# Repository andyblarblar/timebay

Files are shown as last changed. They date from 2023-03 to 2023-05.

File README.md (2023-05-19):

# Timebay

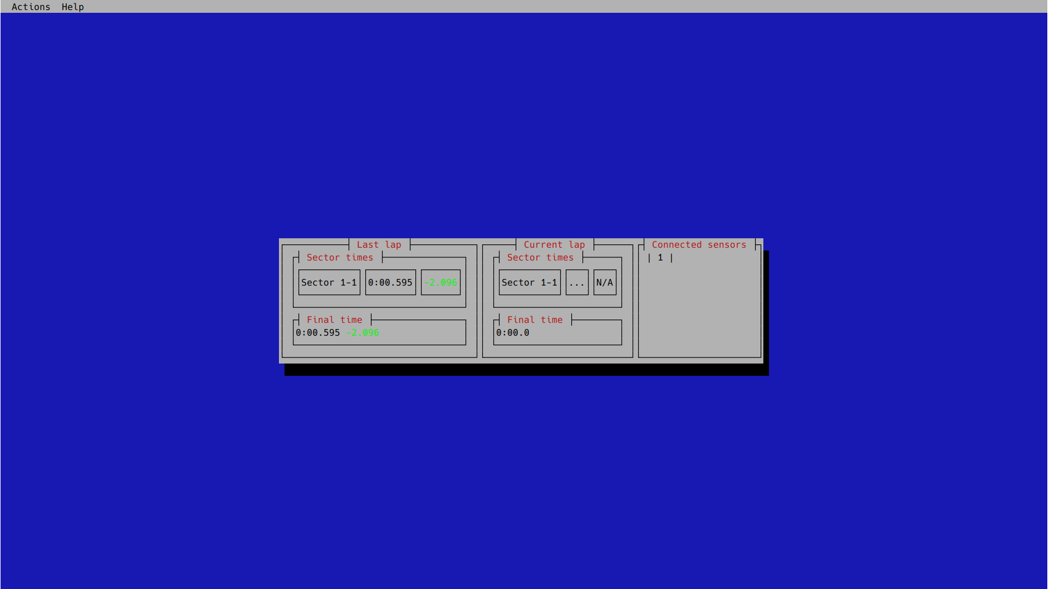
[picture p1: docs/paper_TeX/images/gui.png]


Timebay is a distributed system that provides two services to student vehicles in testing:
1. Sector timing (and splits)
2. Wireless network access

It does this by creating a mesh network of sensor nodes, where each sensor node contains a mesh point for other sensor nodes, 
vehicles, and clients to connect to. Timing data passes through this mesh, as does any user applications used, such as video feeds,
ROS topics and more. To connect to the timing services of Timebay, a TUI is provided.

For more details on the design, operations, and performance of Timebay, please see [the docs](./docs) and [the paper](./docs/Timebay.pdf).

Features:
- **Unlimited Scalability** - Add as many sectors as you need / can afford.
- **Resiliency** - Timebay is designed to do everything it can to ensure your practice day keeps moving. So long as one node keeps working, the system can continue smoothly operating, automatically healing if a node comes back online.
- **Flexibility** - Want to change up your sectors? Go ahead! Just press the zero sensors button when you're done and Timebay will handle all the routing needed to ensure smooth operation.
- **Expandability** - Want to add some other sensor to the network? Go ahead! Timebay provides scripts to connect any other Linux device to the network, allowing access from any other node.
- **Easy Setup** - Just plug the nodes in and go! The system will handle the networking for you.
- **Reasonable Accuracy** - Timebay has been measured to have 10ms error for each sector time in the worst case, and commonly as low as 3ms.
- **Low Cost** - Compared to professional sector timing systems, Timebay is a steal. Using Le Potatoes, the system costs under $100 per node! And remember, with Timebay, you're also getting your networking backbone alongside a sector timing system!
- **Maintainability** - Worried about patching tons of nodes if an issue is found? Don't! Timebay provides an update mechanism to easily update a dozen nodes at a time.

----
What Timebay should be used for:
- Providing online time splits for practice days
- Connecting networked equipment together throughout a circuit, such as cameras or channels for debugging
- Receiving non-critical information from the vehicle in motion, such as data for debugging, or ROS topics for visualisation

What Timebay should not be used for:
- Non-jitter-resistant networking to the vehicle in motion
  - Teleoperation, FPV, etc.
- Replacing a professional system where low error matters
  - Timebay has reasonably low error, but with 3 sectors ~9ms of error can matter a lot in professional events
- Data Collection
  - Timebay is currently designed for online data collection only, no logging is available (this could be added if required)

## Setup and Operation

To set up your own instance of Timebay or maintain an existing one,
please see [this document](docs/le-potato-setup.md).

## End User Instructions

> Required Items:
> - 1 Gateway node
> - 1-many Sensor nodes
> - Computer with TUI installed, and a way to connect an Ethernet cable
> - An Ethernet cable

> Note: None of the nodes are waterproofed (unless additional housing is provided). Check forecasts before deploying Timebay to prevent damage.

Set up:
1. Power the gateway node
2. Place and power all sensor nodes around the circuit, ordered so that they are passed in ascending order (skipping numbers is fine, like 1,2,4,6)
   1. If sensor nodes are not in order, then the system will assume the vehicle is cutting track
   2. Ensure all sensors have a solid object within 10m, so they can properly zero
   3. Ensure all sensors have at least 20cm between the object the sensor is hitting and the vehicle
   4. Ensure laps will take greater than 2s, else the debouncing on the sensor nodes will cause the vehicle to be ignored
3. Connect your computer to the Ethernet port on the gateway node
4. Run the TUI with `timebay_tui 192.168.0.1`
   1. This may display 'Connecting to broker...' if the system has not booted yet, or you have not received an IP. This will resolve itself in minutes. 
5. Wait for all nodes to display in the 'Connected Nodes' panel in the GUI. 
   1. Each node takes about 3 minutes to boot and connect to the mesh, so this may require a wait
   2. If a node does not appear after some time, then ensure that node is powered (indicated by a blinking blue). If it is, attempt to move the node closer to another node.
6. If external nodes are being used, run scripts/run_external_node.bash to connect them (this can be done at any time)
7. The system should now be ready to time. The system will begin when lowest ID node is passed, and automatically continue as laps are completed
   1. If the TUI crashes or seizes for some reason, simply close it and open again. This will lose splits, but will resume operation.

The system can be powered down abruptly and in any order without damage.

## Development

### Rust

The sensor node and client are both implemented in Rust. These are both in the /rust_ws folder, in a Rust workspace.

All of these applications can be developed without the nodes themselves, as they do not assume any hardware.

To run the sensor node using a fake instead of a real tf-luna, compile with the `no_sensor` feature enabled. This will
read a trigger every 3 seconds.

To integration test, there is a node simulator in node_sim. This can be used to test edge cases in the GUI or potential future
consumers of the detection data.

## Docker

Both nodes dockerfiles are at the top level. All files used in them are in the top level /scripts, /configs ect. directories.

Most scripts in /scripts have two versions, one for 802.11s, and one for batman-adv. All scripts for batman will have the 
postfix '_bat'. Both BATMAN-adv and 802.11s have their quirks. 802.11s works much better overall, but is pretty strict when it
comes to compatible hardware. BATMAN on the other hand is very compatible, but suffers from huge packet loss.

For convenience, there are build_x_node.bash scripts to build and tag the nodes correctly during development.

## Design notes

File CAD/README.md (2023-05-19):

# CAD

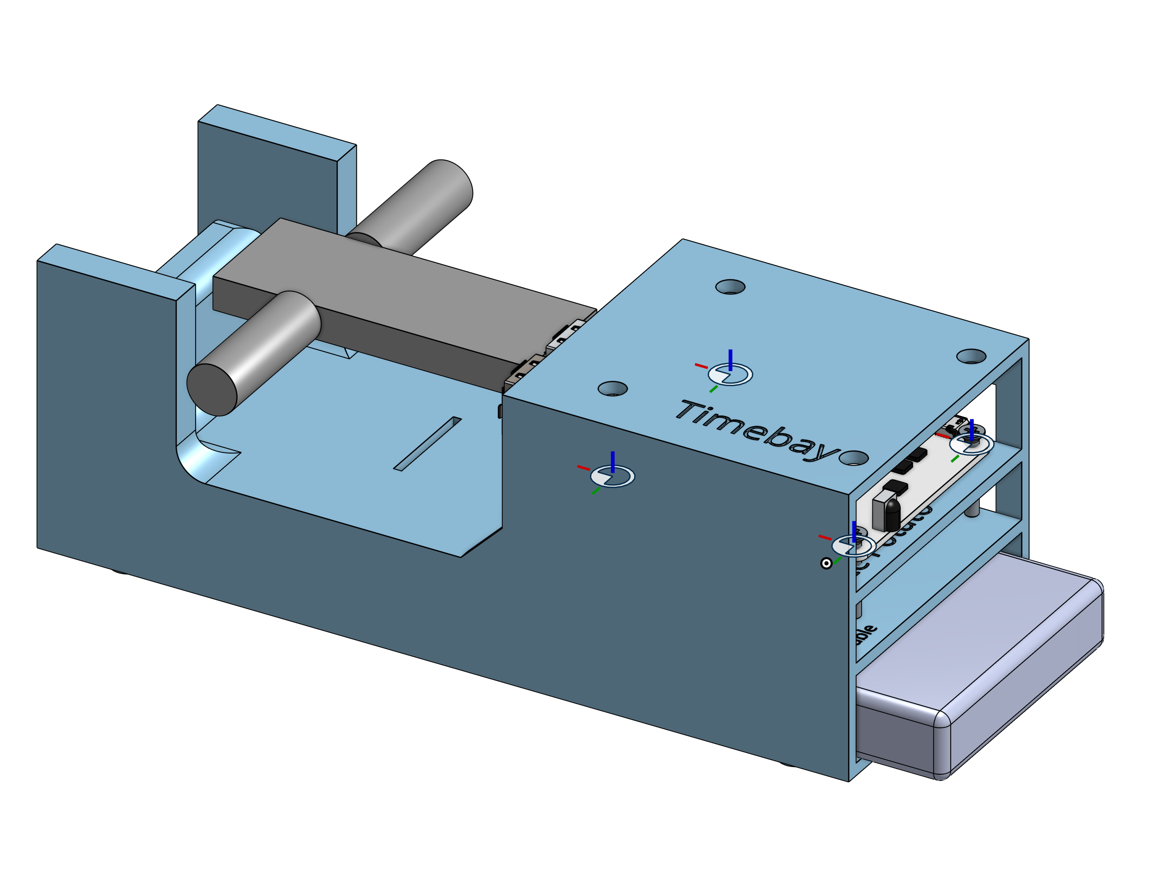
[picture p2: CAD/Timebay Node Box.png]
Box


This directory holds the CAD files for the boxes used to hold nodes.

View the OnShape
source [here](https://cad.onshape.com/documents/eca78c23cf623a8ee2aef306/w/7645614f6dc16000e8edd940/e/3784cc69f371b8e9440601d2).

I recommend printing these vertically if possible, as it significantly improves the print.

The slot in the middle of the box is designed to hold velcro, which can be used to extract the battery if it is pushed
into the
box (insert the Velcro from top to bottom first, then push in the battery, then pull the Velcro to remove battery)

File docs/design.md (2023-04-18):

# Design

This document has some notes on the design of the system

## Sensor node choices

- All mqtt use should be generic over client implementation. This means that we can swap in the case of issues with
  cross compiling ect.
- Dist sensors are debounced to avoid triggering on the same vehicle multiple times
- Mqtt payloads are postcard serialized structs
- Sensor threshold should always be > 160mm, since the sensor has +-16cm accuracy at worst
    - Note the 20cm blind spot, although this shouldn't matter much because the vehicle should never be that close
      anyhow.
- The dockerfile should be cross compilable to other archs, like MIPS
- While the TF-Luna does have an object detection mode that more or less eliminates the need for the dist sensor, I use
  the polling mode anyway, so we can swap to something like an ultrasonic sensor in the future with no code changes.
- Connected messages are sent continuously as a heartbeat, since when they are sent only once a late connecting GUI
  cannot
  discover the node.
- If a node has an internet connection at boot, it will attempt to OTA update itself by git pulling the timebay repo,
  then rebuilding the docker container.

## Networking choices

- Choice of layer 1:
    - 802.11 was chosen for its ability to maintain high throughput, for things like FPV driving
- Mesh interface config is done in the docker container, so that it can be run on any linux system without the need
  to worry about configuring it beforehand.
    - This is possible by using network=host
- ~~While 802.11s was initially chosen, it appears that the ability to bridge mesh interfaces was never actually~~
  ~~implemented~~
  ~~, despite being in the docs. [see](https://www.spinics.net/lists/linux-wireless/msg19548.html).~~
    ~~- This manifested as ARP frames being transmitted across the mesh, but not to the bridge (verified with wireshark).~~
      ~~This prevented eth0 from~~
     ~~being connected to the mesh, as well as DHCP from being served.~~
   ~~- 80211s on linux also seems pretty abandoned, with poor driver support (ex. rpi)~~
- So it turns out that under the rt2080 drivers, bridging is broken. On other drivers though, it works fine.
  - This is very important, since it turns out that BATMAN-adv causes massive packet loss when more than 2 nodes exist in the mesh
  - Because of this, 802.11s is likely the preferred protocol when drivers are available. 
- BATMAN-adv over IBSS is added as an alternative to 80211s as the meshing layer for timebay
    - Running over an IBSS means pretty much any interface can be used, although it does lock us into linux (so no MCU)
    - It also puts [an emphasis](https://www.open-mesh.org/projects/batman-adv/wiki/Wiki) on being able to be bridged,
      so it should solve our 80211s woes there
        - In particular, it's actually interface agnostic, and can even run over bluetooth and ethernet!
    - This is done by just changing the docker entrypoint to a different script, so we don't need duplicate containers
- In order to avoid latency in the system effecting lap times, detection messages will be timestamped globally when the
  detection occurs on device. This relies on
  all nodes having a synchronised clock.

## Client choices

- Client can survive disconnects
    - The current splits however will not, although this shouldn't be an issue since the client will be hardwired
- System can run with 1-2^16 nodes
    - Really only matters that we support the single sensor node case
- Sector notes:
    - Sector are defined by a starting and ending node, where the ending node is the next sector starting node
        - The last segment is an exception, as its end node is the first node.
    - Timing starts when first node is passed
        - Will not start if any other node is passed
    - If this is not the first lap, then immediately start the next lap when the last lap ends
        - This is needed as the last node of the last lap and the first node of this lap are the same, so we need count
          it as a trigger for both
    - Sectors are completed when their end node is triggered
    - If we jump a node, then mark any sector starting at the current segment and up to the segment ending with the node
      triggered as invalid.
        - We keep timing however, so we still get a final result
    - If we go back a node, invalidate the rest of the run
      - This covers the case where the last node dies, allowing the run to be reset to remove the dead node.
    - Node connection, disconnections, and reconnections are implicitly handled
        - New nodes are ignored
        - A node disconnecting will be handled by the following node being seen as a jump, invalidating the disconnected
          nodes sector
        - Because of this a node can disconnect and reconnect in the same run transparently so long as it triggers when
          it should
        - When the lap is done, the next lap will use the currently connected nodes, removing the dead nodes from the last lap.
        - If a new node is connected that becomes the first node, a full lap will be required before this lap can be recorded
          because the lap will be started in sector 2.
    - A run is done when the last non-invalidated segment is complete
- Sector times are calculated by the difference in time between the last completed sector and the next completed sector.
    - This means that if a sector is invalidated, the time spent in that sector will be rolled into the next.
- The client is designed such that it can be started before any other node on a cold start, and passively manage itself
  as the user connects the sensor nodes.
    - This should speed up setup, since one can visually determine if a node is connected by checking the clients screen
      from a distance.
- Client architecture:
    - The client uses a custom Elm like architecture, implemented on cursive, a TUI library.
    - The idea is basically that the gui holds no state, and will be completely redrawn when the backend updates.
        - The backend can only change state on reaction to messages, which are sent from the gui and from external
          sources, like MQTT.
    - The benefit of this system is that the gui will always match the state of the backend, which means that if we unit
      test the backend, that will implicitly also test the gui.
        - It also handles concurrency well, IMO
    - This is actually implemented by message passing between threads
        - The gui runs on the main thread, the backend runs on the backend thread, and async events (MQTT, gui updates
          ect)
          are processed on an eventloop thread.
        - The gui inputs have callbacks that send messages to the async thread
        - The async thread listens to mqtt and gui messages via polling, and merges the various sources to a common
          message
          type sent to the backend thread
    - When the backend thread receives a message, it passes it to an update function, which performs side effects on the
      apps state
        - Update can also return async tasks to run on the async thread, if we have a long-running side effect like
          sending a mqtt message
    - After running update, the whole gui is popped, and a new gui is rendered and pushed.

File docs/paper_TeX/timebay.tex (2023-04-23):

\documentclass[journal]{IEEEtran}
%
% If IEEEtran.cls has not been installed into the LaTeX system files,
% manually specify the path to it like:
% \documentclass[journal]{../sty/IEEEtran}

% Some very useful LaTeX packages include:
% (uncomment the ones you want to load)

% *** MISC UTILITY PACKAGES ***
%
%\usepackage{ifpdf}
% Heiko Oberdiek's ifpdf.sty is very useful if you need conditional
% compilation based on whether the output is pdf or dvi.
% usage:
% \ifpdf
%   % pdf code
% \else
%   % dvi code
% \fi
% The latest version of ifpdf.sty can be obtained from:
% http://www.ctan.org/pkg/ifpdf
% Also, note that IEEEtran.cls V1.7 and later provides a builtin
% \ifCLASSINFOpdf conditional that works the same way.
% When switching from latex to pdflatex and vice-versa, the compiler may
% have to be run twice to clear warning/error messages.

\usepackage{multirow}
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
% LaTeX2e). It also provides a command:
%\fnbelowfloat
% to enable the placement of footnotes below bottom floats (the standard
% LaTeX2e kernel puts them above bottom floats). This is an invasive package
% which rewrites many portions of the LaTeX2e float routines. It may not work
% with other packages that modify the LaTeX2e float routines. The latest
% version and documentation can be obtained at:
% http://www.ctan.org/pkg/stfloats
% Do not use the stfloats baselinefloat ability as the IEEE does not allow
% \baselineskip to stretch. Authors submitting work to the IEEE should note
% that the IEEE rarely uses double column equations and that authors should try
% to avoid such use. Do not be tempted to use the cuted.sty or midfloat.sty
% packages (also by Sigitas Tolusis) as the IEEE does not format its papers in
% such ways.
% Do not attempt to use stfloats with fixltx2e as they are incompatible.
% Instead, use Morten Hogholm'a dblfloatfix which combines the features
% of both fixltx2e and stfloats:
%
% \usepackage{dblfloatfix}
% The latest version can be found at:
% http://www.ctan.org/pkg/dblfloatfix

%\ifCLASSOPTIONcaptionsoff
%  \usepackage[nomarkers]{endfloat}
% \let\MYoriglatexcaption\caption
% \renewcommand{\caption}[2][\relax]{\MYoriglatexcaption[#2]{#2}}
%\fi
% endfloat.sty was written by James Darrell McCauley, Jeff Goldberg and 
% Axel Sommerfeldt. This package may be useful when used in conjunction with 
% IEEEtran.cls'  captionsoff option. Some IEEE journals/societies require that
% submissions have lists of figures/tables at the end of the paper and that
% figures/tables without any captions are placed on a page by themselves at
% the end of the document. If needed, the draftcls IEEEtran class option or
% \CLASSINPUTbaselinestretch interface can be used to increase the line
% spacing as well. Be sure and use the nomarkers option of endfloat to
% prevent endfloat from "marking" where the figures would have been placed
% in the text. The two hack lines of code above are a slight modification of
% that suggested by in the endfloat docs (section 8.4.1) to ensure that
% the full captions always appear in the list of figures/tables - even if
% the user used the short optional argument of \caption[]{}.
% IEEE papers do not typically make use of \caption[]'s optional argument,
% so this should not be an issue. A similar trick can be used to disable
% captions of packages such as subfig.sty that lack options to turn off
% the subcaptions:
% For subfig.sty:
% \let\MYorigsubfloat\subfloat
% \renewcommand{\subfloat}[2][\relax]{\MYorigsubfloat[]{#2}}
% However, the above trick will not work if both optional arguments of
% the \subfloat command are used. Furthermore, there needs to be a
% description of each subfigure *somewhere* and endfloat does not add
% subfigure captions to its list of figures. Thus, the best approach is to
% avoid the use of subfigure captions (many IEEE journals avoid them anyway)
% and instead reference/explain all the subfigures within the main caption.
% The latest version of endfloat.sty and its documentation can obtained at:
% http://www.ctan.org/pkg/endfloat
%
% The IEEEtran \ifCLASSOPTIONcaptionsoff conditional can also be used
% later in the document, say, to conditionally put the References on a 
% page by themselves.

% *** PDF, URL AND HYPERLINK PACKAGES ***
%
\usepackage{url}
% url.sty was written by Donald Arseneau. It provides better support for
% handling and breaking URLs. url.sty is already installed on most LaTeX
% systems. The latest version and documentation can be obtained at:
% http://www.ctan.org/pkg/url
% Basically, \url{my_url_here}.

% *** Do not adjust lengths that control margins, column widths, etc. ***
% *** Do not use packages that alter fonts (such as pslatex).         ***
% There should be no need to do such things with IEEEtran.cls V1.6 and later.
% (Unless specifically asked to do so by the journal or conference you plan
% to submit to, of course. )

\begin{document}
%
% paper title
% Titles are generally capitalized except for words such as a, an, and, as,
% at, but, by, for, in, nor, of, on, or, the, to and up, which are usually
% not capitalized unless they are the first or last word of the title.
% Linebreaks \\ can be used within to get better formatting as desired.
% Do not put math or special symbols in the title.
\title{Timebay: an Ad-Hoc Distributed System For Student Vehicle Testing}

\author{Andrew Ealovega}

\maketitle

\begin{abstract}
The University of Michigan Dearborn features many student vehicle teams that rely on test data to inform their innovations. Currently, each team has their own dedicated systems for testing, of varying quality and price. This paper introduces Timebay, a system that ergonomically provides testing infrastructure that can be shared across teams. Timebay is a network of sensor nodes that provide both online timing data for optimisation, as well as a reliable network connection to vehicles in motion for debugging and other uses. This is achieved by exploiting the observation that these two domains together create an environment compatible with mesh networking technologies, which can be used to enhance the user experience for both use cases. 
\end{abstract}

\section{Introduction}

\IEEEPARstart{T}{he} University of Michigan Dearborn (UMD) plays host to many competitive student organisations.
These organisations challenge students to form cross-functional teams with their peers to approach a common task (such as rocketry, robotics, etc.), before
pitting their solution against those of other schools across the country. Two of these teams, UMD-Racing and the Intelligent Systems Club, will be the focus of this paper.
    
UMD-Racing\footnote{https://umdearbornfsae.weebly.com} is UMD's Formula SAE Combustion team. Their competition has them build, test, and race a formula car over the span of a single school year. As part of their program, UMD-Racing performs extensive testing days to evaluate their work, and practice for competition. These testing days also serve another very important purpose outside of engineering however: driver training. FSAE competitions nearly always feature a kinetic component, where teams actually race their vehicles against each other in various formats. Because these vehicles can be rather challenging to drive, drivers must spend many hours in the vehicle to get used to its handling. The primary measurement of driver skill (although not the sole measurement) is of course lap times, which will become relevant shortly.

The Intelligent Systems Club\footnote{http://www.iscumd.com} (ISC) is UMD's general competitive robotics team. While ISC has competed in many kinds of events in the past, they are currently branding themselves as the schools autonomous racing team. Competing in the fledgling Autonomous Karting Series, ISC's primary project is the creation of a fully autonomous go-kart. Unlike UMD-Racing, ISC's vehicle does not feature a driver whatsoever, instead featuring a powerful, and networked, onboard computer. Like UMD-Racing, ISC performs testing days to evaluate performance. Once again, lap times are a useful metric of overall system performance. A challenge unique to ISC has been access to the onboard computer, since it must be headless. The solution to this classically has been to bring a home router to the testing site, as well as batteries to power it. 

Recently, both teams have run into issues with their testing. First, UMD-Racing currently does not have any sort of timing system, so driver performances are ranked using a manual stopwatch. This is obviously a rather course metric, which also lacks any sort of contextual data about where on course one driver may be performing better than another. Second, ISC lacks any sort of infrastructure for testing their new Kart. All of the prior stated timing issues also apply here, just with evaluating a model rather than a driver. In addition, the team has been aiming to make their systems more ergonomic compared to past projects, networking included. While the past router solution has worked, carrying around a full size router just for a single connection is rather wasteful. In addition, it suffers if the testing area gets too large for the single router to cover, which is more likely this year with the kart than with less mobile robots of the past.

I propose that both of these issues can be solved together, using a system dubbed \textit{Timebay} (a combination of the metric time, as well as highbay, the room on campus where the teams meet). To design Timebay, three primary design goals were identified from the prior requirements:
\begin{enumerate}
    \item Provide granular online lap time data
    \item Provide wide ranging network access to the vehicle
    \item Be reasonably ergonomic, such that those with little knowledge of IT can still operate the system
\end{enumerate}

Before we can begin to attempt to solve these goals together, we first need to investigate existing systems that solve them separately. To do this, we have identified a representative solution for each goal:

\begin{itemize}
    \item Goal 1: Sector timing systems
    \item Goal 2: Mesh networks
\end{itemize}

\section{Existing Solutions}

\subsection{Sector Timing}

In motor sports, a sector refers to a section of the full circuit. Sector times are thus simply the amount of time it took a driver to pass though a sector's bounds. This is similar and somewhat interchangeable with the term time splits or just 'splits'. Such a timing system is often complemented by time deltas, which are the differences in time taken between two laps in the same sector. For example, if a driver discovers a better way to enter a turn, their sector time will go down, and their time delta will report the empirical amount of time saved.

These systems are often used to compare two drivers performances, as well as analyse one's own performance while training. The primary advantage of using a sector timing system over a full course system is the introduction of context to the full lap time, since one can view where time was gained or lost around the course.

Most sector timing systems are implemented using a series of sensors around the course, with some sort of receiver on the car itself. As the car passes a sensor, its time is logged on the car, or alternatively some sort of central computer. An example of such a system is the MoTec BTX and BT2, which is the system UMD-Racing would use without Timebay \cite{motec}. These systems are quite expensive, as seen by the (at the time of writing) \$790.00 price \textit{per transmitter} in the MoTec system.

Upon interviewing UMD-Racing, they explained that the primary use of a sector timing for their student team would be for online information. This is because they already have advanced sensors for tracking position, but this data must be processed over a period of hours following practice. While training drivers, they could utilise the extra information given by a sector timing system to more scientifically iterate improvements. This makes a system like the above MoTec a difficult proposition, since it's a system designed for professional racing with many features UMD-Racing would not use. For UMD-Racing, timing data alone would suffice. 

\subsection{Mesh Networking}
Both teams operate in regions without existing network infrastructure. Thus, when supplying network access to the vehicle, we must utilise ad-hoc networking. One popular approach to ad-hoc networking is mesh networking.
Mesh networks, sometimes referred to as wireless mesh networks (WMN), are a network topology where the network is both managed and created by some set of stations. They are
highly dynamic, and need to handle network degradation or complete node loss gracefully \cite{1509968}. Relevant to this work are mesh networks created using WiFi, for
which there are two prominent implementations: BATMAN-adv and 802.11s.

\textbf{BATMAN-adv}: BATMAN-adv (better approach to mobile ad-hoc networking advanced) is a routing protocol for multi-hop ad-hoc networks \cite{open}. It operates on
OSI layer 2, and is implemented in an in-tree Linux kernel module, which makes it available on any reasonably modern Linux system. BATMAN-adv is rather interesting in that it can run over both wired and wireless networks. To do this, it operates over 
Linux network devices, ultimately providing a network device (bat0) as its API. This allows BATMAN-adv to be used over rather heterogeneous networks. Of note is that this means BATMAN-adv can be used to allow for multi-hop routing at layer 2 in 802.11 IBSS (ad-hoc) networks, which are normally single hop only.

\textbf{802.11s}: 802.11s is the mesh networking protocol implemented into the 802.11 standard itself \cite{article}. Being an 802.11 extension itself, 802.11s operates on layer 2. This does however mean that, unlike BATMAN-adv, 802.11s only works with devices both running WiFi and with drivers that support mesh mode operation. Linux does have support for 802.11s in its native driver stack, however only a few chip-set drivers actually implement this interface \cite{en:developers:documentation:ieee80211:802.11s}. Unlike BATMAN-adv, 802.11s does have the nice advantage of being usable with non-Linux devices, making it better at handling device heterogeneity.

Little existing works investigate the use of these protocols in vehicular mobility. \cite{zeiger2009mobile} Found BATMAN was ill suited to robotic teleoperation with its default settings, but could work spottily with some adjustments. In \cite{8746361}, the authors find BATMAN-adv to be more capable of handling mobile scenarios then rival protocols, given a predictive extension. In \cite{8417706}, the authors investigate 802.11s under high speeds. They found applications resistant to jitter could run over the connection, although jitter sensitive connections like voice and video could not.

For ISC's use case, mobile connections to the vehicle would be highly desirable, but not necessarily required. This is because there are still many use cases where having the vehicle parked somewhere on the circuit with network access would be valuable.

\section{Design}

The design of Timebay is based around the key observation that goals 1, when implemented using a sector timing system, and 2, when implemented as a mesh network, lead to a physically similar topology (visualised in fig. \ref{fig:node_sensor_compare}). This naturally occurs because both systems want to be close to the car. The sector system does this for contextual data, and the mesh network does this for coverage. This makes these two solutions naturally complementary. As the car goes around the circuit, it will pass by sensors to read its sector time. If we also add networking to these sensors, then the car can also move its connection to that local sensor node. Further, these sensor nodes will be spread somewhat equally across the track. Given these nodes form a mesh network, the mesh will be able to form around obstacles that would have otherwise blocked a directional signal from a single station (such as the home router ISC uses).

\begin{figure}[t]
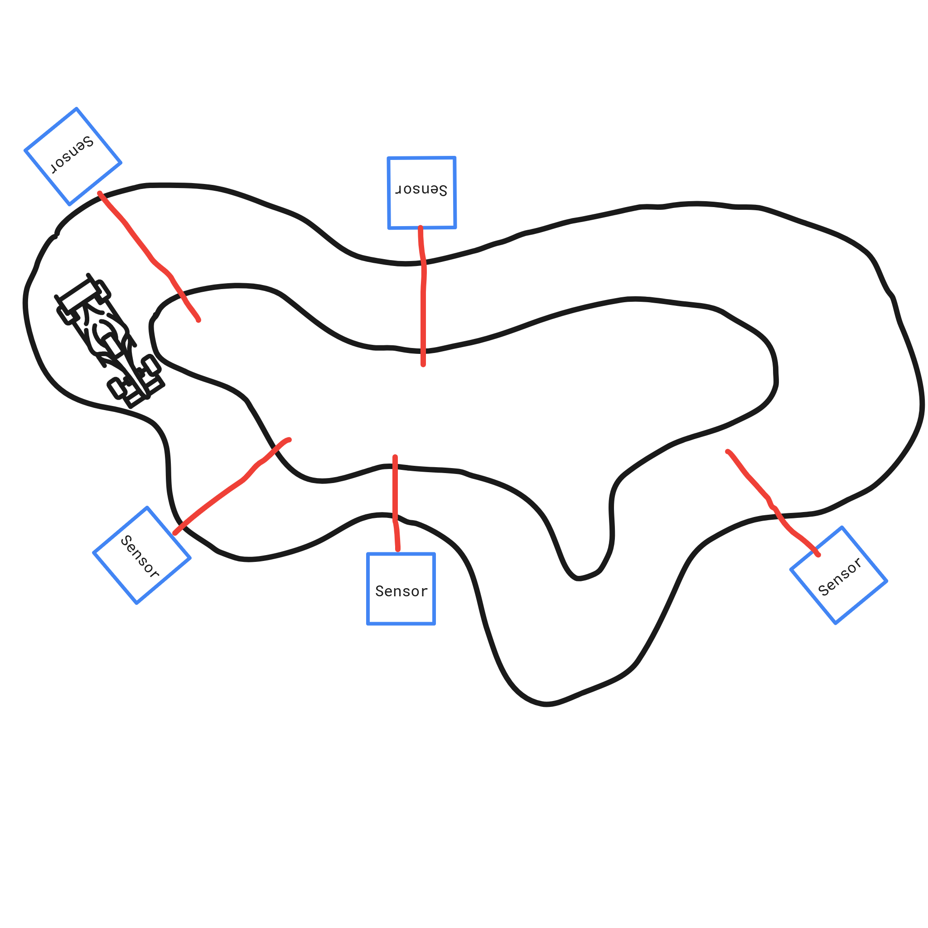
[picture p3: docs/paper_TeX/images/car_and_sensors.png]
    
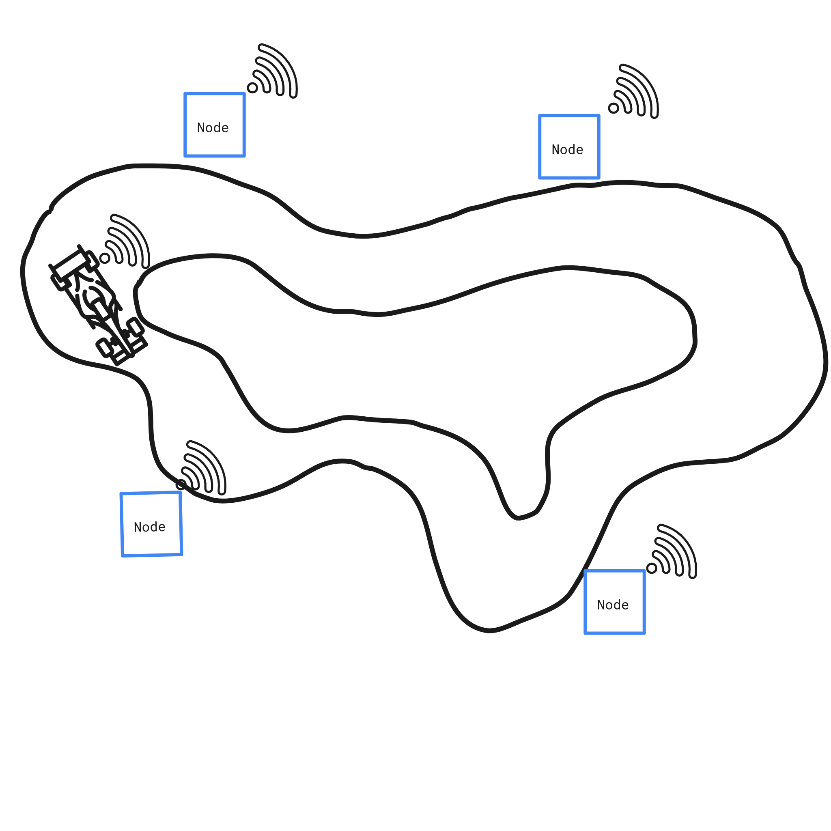
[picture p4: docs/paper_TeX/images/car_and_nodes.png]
    
    \caption{A visualisation of the physical similarities between a mesh network and sector timing system}
    \label{fig:node_sensor_compare}
\end{figure}

This sensor-mesh approach also conveniently handles part of our third goal, ergonomics. Mesh networks are, by definition, self organising. This means that they avoid many of the intricacies of setting up an AP for an end user since they can just be pre-configured by the creator. These mesh networks will also be more resilient to interference, since they can naturally route around something like a locally strong EMF. This should assist in abstracting away the complexities of networking from the user.

There is an issue with using a mesh network approach however. For either use case, an end user cannot get information out of the the network without also using a mesh compatible machine. This goes against our ergonomic goal. To solve this, we introduce a gateway node, which is simply a node that allows for access to the mesh network without participating in the mesh itself. End users will attach their computers to this node, allowing the mesh network to be abstracted away. To aid in 
debugging the mesh network from outside, a GUI will be developed that displays sensor node connection status.

\subsection{Components}
In summary, Timebay is comprised of:

\textbf{Sensor Nodes} - Nodes that handle both detection of a passing vehicle and organisation of the mesh network. Timebay should support 1-many sensor nodes in a network, where each sensor node is allocated a unique identifier. These nodes are fully wireless and battery powered to ease setup.

\textbf{Gateway Node} - A node that serves as the single entry point to the mesh, and Timebay as a whole. This node should have two network interfaces. One participates in the mesh, and the other allows for access to the mesh (via NAT, bridging or otherwise). Any centralised components of Timebay should also run on this server, such as network management utilities or databases.

\textbf{External Nodes} - Guests that participate in the mesh, but are not sensor nodes. These nodes use the mesh simply for its network access to the gateway or other external nodes. An example of an external node would be ISC's onboard PC.

\textbf{Clients} - End user computers that have no mesh compatibility. These are off the shelf laptops that may be running one of many OSes. Clients should connect to the external network interface on the gateway node to access all network resources. A cross-platform GUI application will be provided that will handle access to all of Timebay's timing functions.

\begin{figure}[t]
    \centering
    
    \caption{High level network topology}
    \label{fig:high_level_net}
\end{figure}

\section{Implementation}

\subsection{Hardware}
\textbf{Nodes} - Our node implementation uses the Libre Compute Le Potato single board computer. This is a Raspi3 like board that has an 800Mhz processor, 2Gb RAM, and 1/100 Ethernet. To allow for wireless connectivity, we use ALFA AWUS036ACM (mt7612u chipset) wireless adapters.

\textbf{Sensor Nodes} - Vehicle detection will be preformed using a TF-Luna laser distance sensor. This sensor will be used like a line break sensor, detecting the vehicle when an object is detected some threshold closer than the zero point.

\textbf{Gateway Node} - Clients will connect to the gateway node using it's Ethernet port.

\begin{figure}[t]
    \centering
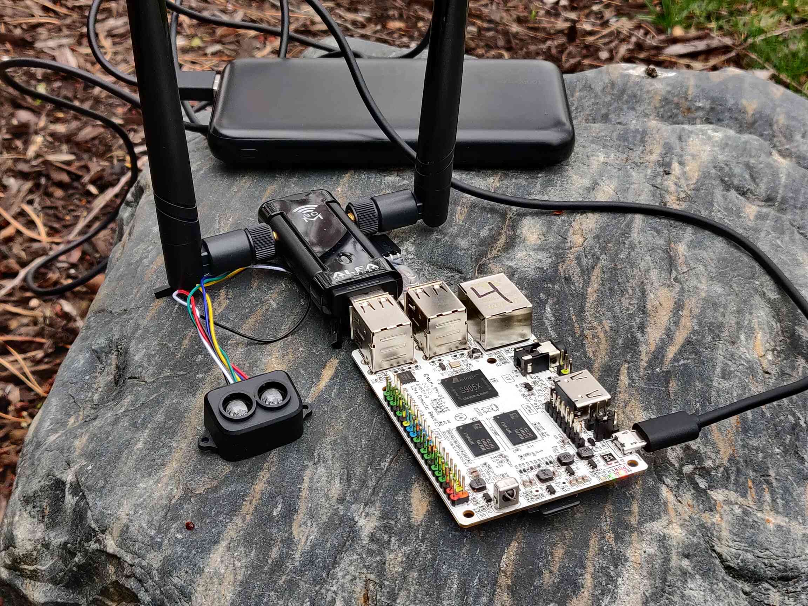
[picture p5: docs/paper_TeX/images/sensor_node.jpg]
    
    \caption{A sensor node}
    \label{fig:node}
\end{figure}

\subsection{Network}

The first key decision required for Timebays network implementation is a choice of physical layer protocol. Three main protocols were considered during this process.

\begin{itemize}
    \item \textbf{WiFi} - High bandwidth commodity standard
    \item \textbf{Bluetooth} - Low bandwidth, low power
    \item \textbf{Zigbee} - Lowest bandwidth, commonly used in mesh networks
\end{itemize}

Overall, Zigbee is likely the most fitting protocol, since it allows for using very low power devices for sensor nodes, and natively supports mesh networks. For Timebays use case however, Zigbee's middling 250Kbps bandwidth is simply too slow for some of the more intense activities ISC may perform \cite{haque_abdelgawad_yelamarthi_2022}. For example, creating an FPV video setup would require bandwidth well into the tens of megabits, which only WiFi supplies. For this reason, WiFi was chosen as the wireless protocol.

For our layer 2 mesh protocol, Timebay implements both a BATMAN-adv and 802.11s option. This is done due to the lack of conclusive evidence supporting either protocol as being definitively superior in the context of mobility. Additionally, little documentation exists regarding the current state of each project, or their associated hardware quirks.

All nodes get dynamic IPs in the 192.168.0.0/24 subnet, allocated by a DHCP server on the gateway node. The gateway node itself has the static IP 192.168.0.1, to allow for connections to centralized resources. DHCP was chosen over static IPs to allow for scaling the number of external nodes in mesh without requiring the user to maintain a record of allocated addresses.

To allow for clients to connect to the mesh network, the gateway node creates a Linux bridge interface between its Ethernet port and its mesh interface. The gateway node is only accessed via the IP address on the bridge, so clients connecting to the mesh can access any other mesh node as if they themselves were on the mesh. This also allows for clients to receive DHCP addresses, as DHCP will flow over the bridge. 

\subsection{BATMAN-adv Configuration}
BATMAN-adv is by default not very mobile friendly, as discussed in \cite{zeiger2009mobile}. Borrowing from that work, we will configure BATMAN to send OGM every 50ms. The goal of this is to minimize the time it takes for the mesh to reconfigure routes, critical to ensure dead nodes are routed around and mobile external nodes quickly change mesh links. To aid in this, OGM aggregation is also disabled, as recommended by the BATMAN-adv docs \cite{tweaking}. Both of these configurations will likely lower throughput, but should hopefully improve persistence in exchange. Following the results of \cite{8421863}, we will be using BATMAN IV over V.

\subsection{Sensor Node Communication}

All data related to the timing features of Timebay are broadcast across the network using MQTT. MQTT was chosen in this case not for its low bandwidth requirements (although this is nice), but rather its convenient pub-sub architecture which naturally mixes well with our highly dynamic network topology. The MQTT broker for Timebay is hosted on the gateway node.

The following topics are used:

\textbf{/connect} - Published to by nodes when they connect or reconnect to the broker. Nodes are allowed to publish to this topic when already connected, as a sort of heartbeat.

\textbf{/disconnect} - Published to by nodes when they disconnect from the broker, via LWT.

\textbf{/zero} - Causes all sensor nodes to zero their sensors.

\textbf{/sensors/detection} - Published to when a node detects a passing vehicle.

\begin{figure}[t]
    \centering
    
    \caption{Timebay network implementation}
    \label{fig:network_impl}
\end{figure}
\subsection{Time}

As the name would suggest, time is rather important in Timebay. When sensor nodes send their data to the client to create sector times, we need to ensure that the client has an accurate estimation of the time that detection actually occurs. There are two ways to approach this problem:
\begin{enumerate}
    \item Timestamp when we receive sensor detections on the client
    \item Timestamp before we send the detection over MQTT, on the sensor node
\end{enumerate}
When evaluating this issue, it's important to remember that what we need to combat here is not the offset between the client and sensor nodes, but rather the \textit{offset} between each of the sensor nodes with respect to other sensor nodes. This is because lap times on the client are stored as absolute time values of the start and end of the sector. If one node's time has error from either approach, and that error is different than the error of any other node (what I call offset), the lap time will be inaccurate. 
From this view, it should be obvious that approach 1 is not viable. This is because every node on the network will naturally have different network latencies to the client, since synchronising latencies is not the goal of a mesh network. For approach 2, network latencies are not a direct issue. Instead, what adds offset is clock desyncronisation (or rather, clock offset as the term is normally used). Because the SBC's used for sensor nodes do not have a RTC, this necessitates the use of a clock synchronisation solution. 

Clock synchronisation in WSN is a well studied area \cite{9297296} \cite{elson2002fine} \cite{ping2003delay} \cite{maroti2004flooding}.
While these approaches do show promise, unfortunately few have open implementations, especially on Linux. Because we lack the resources to implement one of these protocols ourselves, we decide to simply use NTP, the traditional time synchronisation protocol on the Internet. As discussed in \cite{9297296}, an issue with NTP in mesh networks is the potential for asymmetrical latencies in RTTs. To help curb this issue, we chose Chrony as our NTP implementation. Chrony uniquely supports estimating delay asymmetry in its connections, going beyond the requirements of NTP itself \cite{RFC5905}.

Clock synchronisation in Timebay is implemented by synchronising all nodes to the gateway node, since that will be the node that is always present. Because we only care about reducing the offsets between sensor nodes, it does not matter that the gateway node itself may be desyncronised. Accordingly, Chrony is configured to use its local mode, which will serve NTP using the local clock as if it was synchronised. We also declare the servers stratum as 1, since we want all nodes to see the gateway as authoritative. Each sensor node runs Chrony configured to only access the gateway's server, forcing the clock to step if error is greater than 1 second. This is done in hope of forcing fast convergence on system setup, since all nodes will be greatly desynced on boot due to the lack of a RTC. 

\subsection{Sensor Node Detection}

The sensor node vehicle detection code is implemented as a Rust executable. Using the Tokio reactor, it polls over both an MQTT channel and the laser rangefinder concurrently, zeroing the sensor on MQTT command or sending a detection report to MQTT respectfully.

When detections have not occurred for some period of time (currently 3s), sensor nodes will send a heartbeat message on /connect. This is done not to tell if a node is disconnected, as MQTT does that with its own heartbeats, but rather to allow for late-joining clients to discover sensor nodes without requiring those nodes to have a detection.

\subsection{Deployment}

All Timebay nodes are implemented as Docker containers to help abstract over hardware heterogeneity, as well as to ease the difficulty of adding new sensor nodes. These containers are set up to boot on board restart via cronjob.

Because we need to access wireless interfaces from the container, we disable most virtualisation features of Docker. This involves running the container as privileged, using host networking, adding SYS\_TIME capability (required for NTP), and mounting /dev/.

To ease updating potentially many nodes, we set up a sort of 'OTA' update system. When a node boots, we configure its Ethernet port with DHCP if a carrier is available. In its bringup script, we fetch the Timebay repo's upstream. If we have a carrier on eth0 and the remote is ahead of HEAD, then we pull the remote and rebuild the docker container. This means that to update many nodes, one simply needs to plug them all into a switch and supply power.

The general boot process for sensor nodes is:
\begin{enumerate}
    \item Run bash script that git pulls Timebay, and rebuilds the docker container if new changes were pulled
    \item Run docker container
    \item Find a mesh/IBSS compatible interface by scraping iw output
    \item Use iw to set the device to IBSS/Mesh mode
    \item If using BATMAN-adv, setup bat0 interface
    \item Start dhcpcd to get IP address
    \item Start sensor node executable
\end{enumerate}

\subsection{GUI}

The client GUI application is also implemented in Rust, and utilises shared components with the sensor node. The GUI implements all of the actual application logic for sector timing, aggregating data collected from the MQTT broker. Sectors are defined by pairs of nodes starting at the lowest node id and pairing until the last node, which is paired with the initial node id. Each sector begins timing at the end trigger of the last sector, updating the GUI as the course is completed. 

If the car skips a node, the time spent in the sector is simply rolled into the next sector, and the skipped sector is marked invalid. This transparently handles nodes disconnecting, since they will simply be skipped. The alternative would be to invalidate the sector eagerly when the node disconnects but before the car passes it, but this idea was discarded as it complicates the logic of the node coming back online. By treating disconnected nodes as if they were skipped, we optimistically give the node a chance to reconnect with the network without any sort of special logic.

Should the nodes clocks become desynced, it is possible for the GUI to detect the detection timestamps going back in time. If this occurs, the current sector is marked as invalid. 

When a lap is completed, the GUI calculates the complete lap time and moves the splits to one side of the screen, and then displays the time deltas with respect to the prior lap.

Also included in the GUI is a display of all currently connected nodes, as well as a button to zero the sensors. Nodes will display as connected as soon as they send a message to /connect, and will show as disconnected 10 seconds after disconnecting, since we have configured a 10s TTL.

In an attempt to make this GUI as cross platform as possible, it is actually implemented in the terminal, making it a TUI. This avoids linking with platform specific GUI libraries, increasing the chance of the GUI remaining compatible on future, unknown OS versions.

\begin{figure}[t]
    \centering
    
    \caption{Timebay's GUI connected to a single sensor node}
    \label{fig:gui}
\end{figure}

\subsection{Ergonomics}

Timebay's third goal, ergonomics, is primarily achieved by designing the network to be as self operational as possible. For example, all mesh networking is abstracted away by the gateway node. If a node disconnects, one simply needs to wait for it to re-mesh, since the GUI will automatically handle how that addition or reduction of a node will impact lap times. If the layout must be changed, all the user must do is press the zero sensors button in the GUI and the system will be operational again. Mobile batteries are used to power the nodes as opposed to LiPos to allow for easy recharging of nodes by non electrical members.

In addition to these and many more design choices, we make a point to supply ample documentation of the system. This is important, since the student teams have very high turnover, and organisational knowledge around tools is very volatile. In particular, instructions to replicate the current implementation are provided, as well instructions for operation, troubleshooting, and development. To ensure these are not lost while the hardware remains in use, Timebay is open sourced via a GitHub repository\footnote{https://github.com/andyblarblar/timebay}.

\section{Evaluation}

\subsection{Startup time}
First, we will evaluate the startup time in optimal conditions. To measure this, we set up three sensor nodes in a 3m circle around the gateway node attached to a client. A timer is started on the computer, then all nodes are turned on. With the GUI open, we wait until all nodes are displayed in the connected nodes table. The results are shown in Fig. \ref{tab:startup}. Note that this includes the time for:
\begin{enumerate}
    \item Booting Linux
    \item Starting Docker
    \item Connecting to mesh
    \item Getting IP over DHCP
    \item Connecting to MQTT
\end{enumerate}
The average startup time was 3:51 for BATMAN, and 3:20 for 802.11s. Upon investigating the boot logs, it appears that approximately 2:40 of this boot time is spent booting the host OS. This is likely due to a misconfigured service. Because both protocols use the same Docker container, the consistently faster boot times on 802.11s is likely due to properties of its mesh. In particular, DHCP is a likely candidate for this lost time. As we will see later, BATMAN-adv has very large packet loss. DHCP requests addresses using a UDP broadcast. Given this best effort approach, dhcpcd's exponential back-off on failure, and the large packet loss, DHCP can take quite a while to gain an address in BATMAN-adv meshes. This was verified by Wireshark analysis, where DHCP requests could be seen leaving the node but not receiving a response. This could also explain the greater variance shown in the BATMAN-adv results.

\begin{figure}[t]
\begin{tabular}{|l|l|}
\hline
\textbf{Trial (BATMAN-adv)} & \textbf{Time Till complete} \\ \hline
1              & 3:30                        \\ \hline
2              & 3:55                        \\ \hline
3              & 3:44                        \\ \hline
4              & 4:21                        \\ \hline
5              & 3:44                        \\ \hline
\end{tabular}

\begin{tabular}{|l|l|}
\hline
\textbf{Trial (802.11s)} & \textbf{Time Till complete} \\ \hline
1              & 3:11                        \\ \hline
2              & 3:20                        \\ \hline
3              & 3:25                        \\ \hline
4              & 3:20                        \\ \hline
5              & 3:24                        \\ \hline
\end{tabular}
\caption{Timebay startup times}
\label{tab:startup}
\end{figure}

\subsection{Clock Synchronisation}
Next, we will verify that nodes are being synchronised. This test can be seen as a validation of goal 1, since the sector timing logic works as expected, leaving only the clock synchronisation as a potential issue. This is done by placing two sensor nodes next to one another, then dropping a piece of cardboard in front of them. Because the nodes should trigger at roughly the same time, we can compare the GUI's received timestamps to find the offset of the clocks, and thus the error our timing system will see per sector. This process is begun first by rebooting the nodes to force a fresh NTP state, then collecting five samples when the nodes appear in the GUI. The results of this experiment are displayed in fig. \ref{tab:times}. Note that stamps include only the nanoseconds component, as no readings had greater than a second of error. Offsets are rounded to the ms as our testing apparatus does not have ns accuracy. 

These results show us a few things. First, our aggressive stepping of clocks until second accuracy is achieved has achieved its goal of getting the clocks reasonably synchronised within a short period of time. Second, even with very little time to converge, both protocols have an acceptable level of error. 802.11s especially, with all measurements under 10ms. While this advantage could be from NTP having issues contending with BATMAN's packet loss, our testing apparatus has too much potential for procedural error for this to be conclusive.

\begin{figure}[t]
\begin{tabular}{|l|l|l|l|}
\hline
\textbf{BAT} & \textbf{Node 1 stamp} & \textbf{Node 2 stamp} & \textbf{Offset} \\ \hline
1              & 133668199ns           & 158070397ns           & 24ms            \\ \hline
2              & 568918805ns           & 570767970ns           & 2ms             \\ \hline
3              & 728301891ns           & 746114176ns           & 18ms            \\ \hline
4              & 503307445ns           & 501268735ns           & 2ms             \\ \hline
5              & 331404650ns           & 335236888ns           & 4ms             \\ \hline
\end{tabular}

\begin{tabular}{|l|l|l|l|}
\hline
\textbf{802.11s} & \textbf{Node 1 stamp} & \textbf{Node 2 stamp} & \textbf{Offset} \\ \hline
1              & 710317045ns           & 758237086ns           & 8ms            \\ \hline
2              & 321956813ns           & 334979791ns           & 1ms             \\ \hline
3              & 409371012ns           & 430514388ns           & 2ms            \\ \hline
4              & 328401762ns           & 355385103ns           & 3ms             \\ \hline
5              & 716304263ns           & 731996424ns           & 2ms             \\ \hline
\end{tabular}
\caption{Timebay clock synchronisation offsets}
\label{tab:times}
\end{figure}

\subsection{Packet Loss}
While performing other tests, many were failing to pass due to massive packet loss. To investigate this issue further, we test the packet loss under various setups to find any patterns. For all of these configurations, the client is connected to the gateway node and SSHs into it. From the gateway node, we use ubuntu's ping utility to test the packet loss to one of the sensor nodes until 150 sequences are reported. For each configuration, we repeat this test for 1, 2, and 3 connected sensor nodes. The results of these tests are shown in fig. \ref{fig:packetloss}.

First, we test BATMAN-adv with 50ms OGM, which was the configuration initially proposed. As shown in fig. \ref{fig:packetloss}, there is a massive jump in packet loss when a second node is added, with a further increase with a third. To investigate if this issue was caused by our aggressive OGM rate, we run the test again with 500ms OGMs. Once again, packet loss jumps massively when a second and then third node are added, although less so than with the 50ms OGM. To ensure this isn't a fundamental issue with our system, we finally repeat the test with 802.11s. These results are a little hard to view in the chart, since there is \textit{literally no} packet loss, regardless of node count. This result was quite surprising, since other literature on BATMAN-adv does not document packet loss issues. The packet loss only begins once IP data begins to be sent, not when the IBSS forms. Because of this, its possible this is a misconfiguration of BATMAN-adv, although we use all default settings aside from OGM rate, which makes this unlikely.

\begin{figure}[t]
    \centering
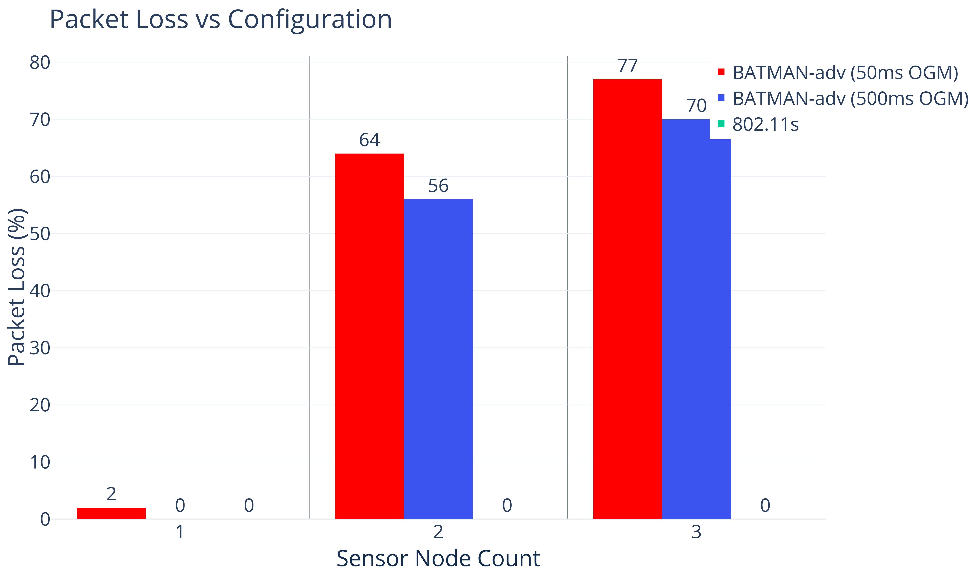
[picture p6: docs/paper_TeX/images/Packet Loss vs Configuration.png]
    
    \caption{Packet loss under various configurations}
    \label{fig:packetloss}
\end{figure}

\subsection{Throughput In Motion}

\begin{figure}[t]
    \centering
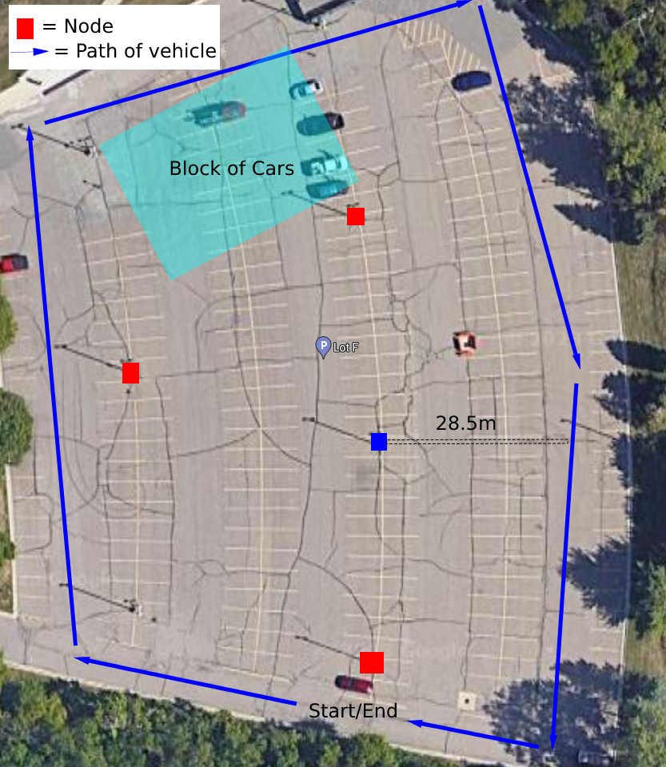
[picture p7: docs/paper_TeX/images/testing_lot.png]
    
    \caption{Testing setup for throughput tests}
    \label{fig:lot}
\end{figure}

Finally, we will evaluate throughput of the mesh with a vehicle in motion. This can be seen as a validation of goal 2. Unfortunately, neither teams vehicle was available for testing. As a stand in, a collaborator's \textit{2023 Ford Maverick XLT 2.0L EcoBoost AWD} will serve as our vehicle. To ensure fair results, we have a laptop held in the bed of the truck to prevent the body from blocking signals. This is important because both student vehicles allow for unobstructed antennas. Testing was done on a parking lot on campus, with 3 sensor nodes and the gateway node spread throughout. The distribution of these nodes is displayed in fig. \ref{fig:lot}. The laptop held in the bed will be simulating the onboard PC of ISC, connected to the mesh as an external node. We will only perform these tests using 802.11s, since BATMAN-adv's packet loss was too high to perform the test with 5 total nodes. For each test, the vehicle will drive the perimeter of the lot while iperf3 runs a TCP bandwidth test of the network between a client connected to the gateway and the external node on the vehicle. Pings will run for all tests to collect aggregate latency measurements. The results of these tests can be seen in fig. \ref{fig:throughput}.

\begin{figure*}[t]
    \centering
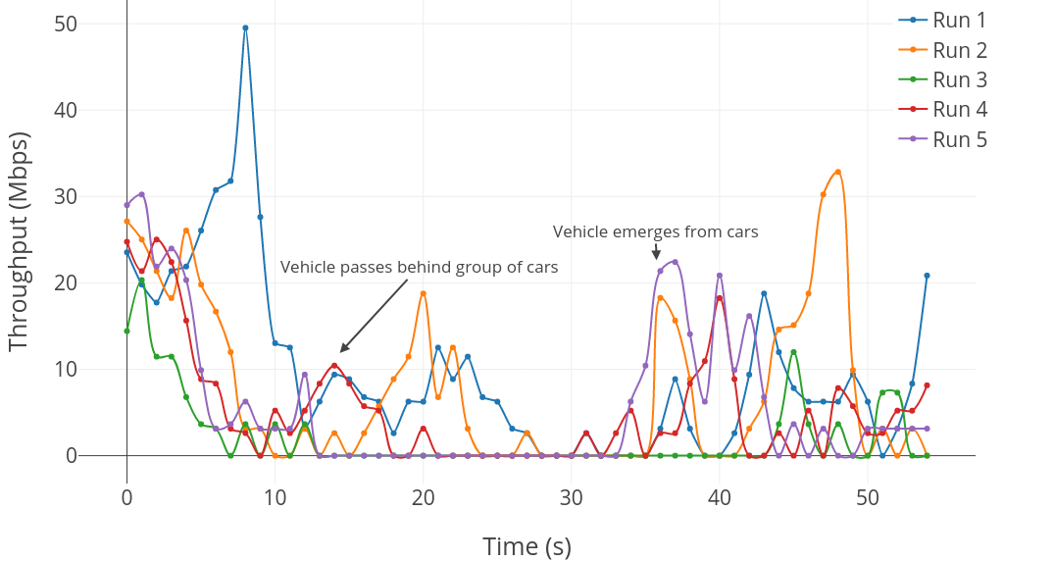
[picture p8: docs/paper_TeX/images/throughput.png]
    
    \caption{Throughput of the mesh with vehicle in motion}
    \label{fig:throughput}
\end{figure*}

As can be easily observed, Timebay has very large amounts of jitter while in motion. This was not unexpected, and tracks with the results of \cite{8417706}. This can be seen in the latency results, where we see a minimum RTT of 1.3ms, a max of 1800ms, an average of 68ms, and a standard deviation of 123ms. From the period of around 15s - 34s, a large drop in throughput, or even the connection, can be seen in all runs. This is due to a large block of parked cars in the lot fully obscuring the vehicle from all nodes. This gives us the opportunity to observe the mesh reforming under motion, which it does very smoothly shortly after the vehicle emerges at approx. 35s. Note that because of this, 35s onwards is the most representative of an average use case, as the vehicle is in motion and in range of at least one node. This range still shows large variance in throughput, ranging from 2Mbps to 20Mbps depending on the run. Overall, these results show that Timebay is not suitable for real time data transfer from an external node, such as for teleoperation. It is, however, capable of transferring data at reasonable speeds (faster than alternative wireless standards) in jitter durable applications. An example of this could be viewing ROS topics from the external node in Rviz, where latency is less of a concern than persistence and reasonably fast speeds.

It is worth pointing out that the above results apply to a vehicle in motion only. While stationary, Timebay can maintain consistently high speeds, sometimes even pushing up against the bandwidth of the 1/100 gateway link. This applies to both the vehicle while stationary, as well as other possible uses of external nodes, such as remote terminals around the circuit.

\subsection{BATMAN-adv vs. 802.11s}
As can be seen throughout the evaluation, the choice of BATMAN-adv vs. 802.11s significantly changes the behavior of Timebay. Of course, Timebay can only use one of these protocols at a time, so it is worthwhile defining a default.

A running theme throughout the creation of Timebay was the mesh protocols acting significantly differently given different hardware. Initially, the system used wireless adapters in the rt2800 chip-set family. While using these drivers, 802.11s was unable to bridge with the Ethernet port on the gateway, preventing the use of 802.11s in Timebay. When the project moved to adapters that used the Linux mt7x drivers for unrelated reasons, 802.11s was fully operational. This poses a significant issue for recommending a protocol, since reproductions of Timebay in the future may outright not function if chip-sets change even in vetted adapters. Unfortunately, BATMAN-adv was nearly unusable with multiple nodes in either setup due to its massive packet loss. However, it was capable of bridging even with the rt2800 adapter. Awkwardly, this leaves BATMAN-adv with a niche where it is still technically better than 802.11s, by virtue of running at all.

Overall then, 802.11s is currently far and away the better implemented protocol on Linux, so long as you have an adapter with the correct chip-set. If you don't, then BATMAN-adv can be used as a fallback, although it shouldn't be used with more than one sensor node.

\section{Conclusion}

\subsection{Limitations}

\subsubsection{Security}
Timebay lacks any security whatsoever. This means that anyone is capable of connecting to the mesh and accessing its resources. Realistically, this primarily makes external nodes like ISC's PC vulnerable to external connections if not secured. For a more professional application, this would also make the system vulnerable to passive and active attacks on the sensor detection times over MQTT. This could be an issue if say, a formula team is practicing around competitors. For the intended use case, I do not consider this a large issue, since the onboard PC is already secured and messing with lap times is harmless. The system should be amendable to hardening many of its interfaces, such as requiring a password for MQTT and encrypting WiFi using 802.11s's SAE \cite{en:developers:documentation:ieee80211:802.11s}.

\subsubsection{SBCs}
Timebay, by its reliance on Linux, requires the use of SBCs that are likely far more powerful than needed. This reliance comes from a few sources:
\begin{enumerate}
    \item Mesh Implimentations
    \item Current sensor node implementation codebase
    \item NTP
\end{enumerate}
While 2 could be programmed away, 1 and 3 are far more difficult. Both mesh algorithms and clock synchronisation suffer from a lot of theoretical algorithms but a lack of implementations. Even when implementations are available, they are often for a particular embedded OS, lowering the odds of the other system also being available. Should this issue be resolved, Timebay could likely be implemented using a micro-controller like the ESP32 as the sensor node platform, although throughput would need to be re-verified.

\subsection{Future Work}
Timebay is still a very young system, and has many areas that could be significantly improved given future work. 

\subsubsection{802.11s Parameters}
All tests were performed using default 802.11s parameters, largely due to a lack of time for iteration. These parameters, especially those controlling the HWMP, can likely be significantly optimised for the moving vehicle scenario. 802.11s also natively supports the concept of gateway nodes, something that we do not utilise in this work.

\subsection{WiFi}
All mesh configurations currently use 2.4ghz channel 5 with HT40+ for their underlying WiFi connections. Channel 5 was chosen after a site survey of campus found it to be the least congested. Even with this choice, the 2.4ghz spectrum is very polluted from various industrial machines around campus. Future work should investigate both the use of the 5ghz spectrum as well as various channel widths to potentially increase throughput and other metrics.

\subsubsection{Hardware}
To improve ergonomics, Timebay could greatly benefit from standardised boxes for the nodes. This would improve setup times, lower the chance of environmental damage, and overall improve ease of use. These should be able to be constructed with 3d printers, allowing us to open source the design alongside the codebase.

\subsection{Summary}
To aid two student teams at the University of Michigan Dearborn, we analyse some shared deficiencies between the teams. This uncovered the need for both a granular timing system, and a large-scale network for vehicle connections. To solve both issues together, we combine the existing solutions of sector timing and mesh networking into one system, called Timebay. Upon evaluation, Timebay is shown to excellently fulfill its timing duties, with only a 3.2ms average error per sector using 802.11s. The mesh network is shown to provide network access to the vehicle while still and within the range of a node, but suffers from jitter in throughput and latency while in motion. Overall, Timebay should adequately address the needs of UMD-Racing, and greatly improve the networking conditions of ISC. Future work should focus on improving network conditions while the vehicle is in motion, potentially opening up new avenues of use for Timebay within ISC.

% Can use something like this to put references on a page
% by themselves when using endfloat and the captionsoff option.
\ifCLASSOPTIONcaptionsoff
  \newpage
\fi

\bibliographystyle{IEEEtran}
\bibliography{bibtex/bib/timebay}

% that's all folks
\end{document}

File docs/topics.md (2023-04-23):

# Topics

## /connect
- Use: Published to continuously by nodes while they are connected to the broker.
- Qos: Exactly Once
- Format:
  - node_id: int - Node id of the connecting node

## /disconnect
- Use: Published to by nodes when they disconnect with the broker. This is done via LWT.
- Qos: Exactly Once
- Format:
    - node_id: int - Node id of the node

## /zero
- Use: Causes all nodes to zero their sensors
- Qos: At Least Once
- Format:
  - (empty)

## /sensors/detection
- Use: Published to when a sensor detects a passing vehicle
- Qos: Exactly Once
- Format:
  - node_id: int - Node id of triggered node
  - stamp: tv - unix stamp of the detection
  - dist: int - distance in mm the detection occurred at

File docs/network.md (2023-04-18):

# Network

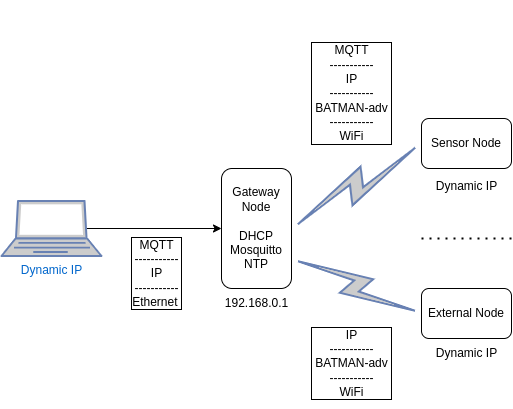
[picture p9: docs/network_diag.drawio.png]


## Mesh (Layer 2)

A mesh network is created between all the sensor nodes and the gateway node.
This mesh is formed transparently at the link layer for all implementations. Notably, this means that timebay is really
running two routing protocols, one at layer 2, and one at layer 3.

Timebay currently offers two mesh implementations:

- 802.11s
- BATMAN-adv

### 802.11s

802.11s is the multi-hop mesh networking standard built into 802.11 itself. 802.11s requires driver support per
interface, so realistically only a few Wi-Fi chipsets on linux are easily capable of joining an 802.11s mesh, despite
its standardisation.

Theoretically, 802.11s should support more _device heterogeneity_ among the sensor nodes, since it can be implemented in
hardware
on something like an MCU. Due to its lack of open implementations however, this doesn't pan out for timebay, so all
nodes need
to be running linux.

Mesh support is super spotty, with some drivers that claim to support mesh point (rt2080) not fully implementing the protocol.

### BATMAN-adv

BATMAN-adv is a third party layer 2 meshing protocol that actually predates 802.11s.

The biggest downside with using BATMAN is that it is built into the linux kernel. While this is great for use on linux
SBCs
since any docker container can access it, this does lock us out of using an MCU for any mesh point.

What BATMAN does allow for however is much better handling of _network heterogeneity_, since it can operate over any
linux interface.
This means that under the hood BATMAN is really just a method of turning a series of single hop connections into a large
multi-hop network.
This means that it is possible to run BATMAN networks over ethernet or even bluetooth alongside 802.11, which provides
some exciting
possibilities. More practically though, this means that one can use IBSS mode stations rather than mesh ones, greatly
increasing the variety of network adapters usable.

Another nice feature of BATMAN is that it appears in linux just as a normal interface (commonly bat0). This makes it
nice
to debug, but also means that we can directly bridge the interface without anyone batting an eye. This is used on the
gateway
node, and works very smoothly.

Unfortunately, BATMAN-adv in my experience has issues with something causing massive packet loss. This may be an instance
of the hidden terminal problem, but I'm not certain. While this doesn't make BATMAN unusable, it nearly does.

## IP

To provide TCP/IP networking over the mesh (required for MQTT and clients), the gateway node will also host a DHCP
server.
All sensor nodes and clients will use this DHCP server to get addresses in the 192.168.0.0/24 range, while the gateway
node will have a static IP of 192.168.0.1/24 on its bridge interface.

Because the mesh network operates on layer 2, both ARPs and DHCP discover packets will flow throughout the network fine.

## Bridge

The gateway node bridges its mesh and ethernet interfaces to allow for the end client to both connect to the MQTT broker
and nodes in the mesh. This could be used for example to connect to a camera on the car from a laptop, to facilitate an
FPV setup.

## Time

Because our system relies on timestamps to ensure proper lap times, we need to ensure all sensor nodes have synchronised 
system clocks. To achieve this, the gateway serves NTP using chrony, spoofing a stra 1 server. This makes it an authoritative
NTP server (although it has no right to be) within the timebay network. This is fine, because the only thing that matters 
in our case is that the sensor nodes are synced relative to each other, not real time (or even the clients time). Chrony
is also run on the sensor and external nodes as a client to the gateway server, allowing for stepping the system clock
relatively aggressively, so we converge within the lifetime of the setup of a timebay session.

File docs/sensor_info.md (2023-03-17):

# Sensor Info
This document holds some notes on the TF-Luna laser rangefinder

## Data
- Claimed range: 0.2m - 8m (indoors and with white object)
  - 0.2m-3m for 10% reflectivity black object
- Accuracy: +-6cm in range 0.2m-3m, +-2% in range 3m-8m
  - +-16cm at worst
- Units: cm (says it can be configured)
- Rate: 100Hz (can be configured 1-250Hz)
  - Higher rates lower accuracy
- Has a mode to use single frequency, which requires you to only hit things under 15m, but
allows for reading darker objects.
- Supports a mode that reads only occasionally, to lower power.

## Format
- There are many kinds of data frames and control frames
- Control frame:
  - 0: 0x5A
  - 1: Len (4-255) - Length of bytes from head to checksum
  - 2: ID - Indicates payload format
  - 3-Len-2: Payload - Data segment
  - Len-1: Checksum - Lower 8 bytes of the sum from Head to payload
- 

## Electrical
- Vcc = 5v
- 3v3 TTL
  - Same as Pi
- Peak current = 150mA@5v
- Avg current = <70mA@5v (assuming continues ranging)
- Pins:
  - 5v
  - Rx
  - tx
  - gnd
  - none
  - none

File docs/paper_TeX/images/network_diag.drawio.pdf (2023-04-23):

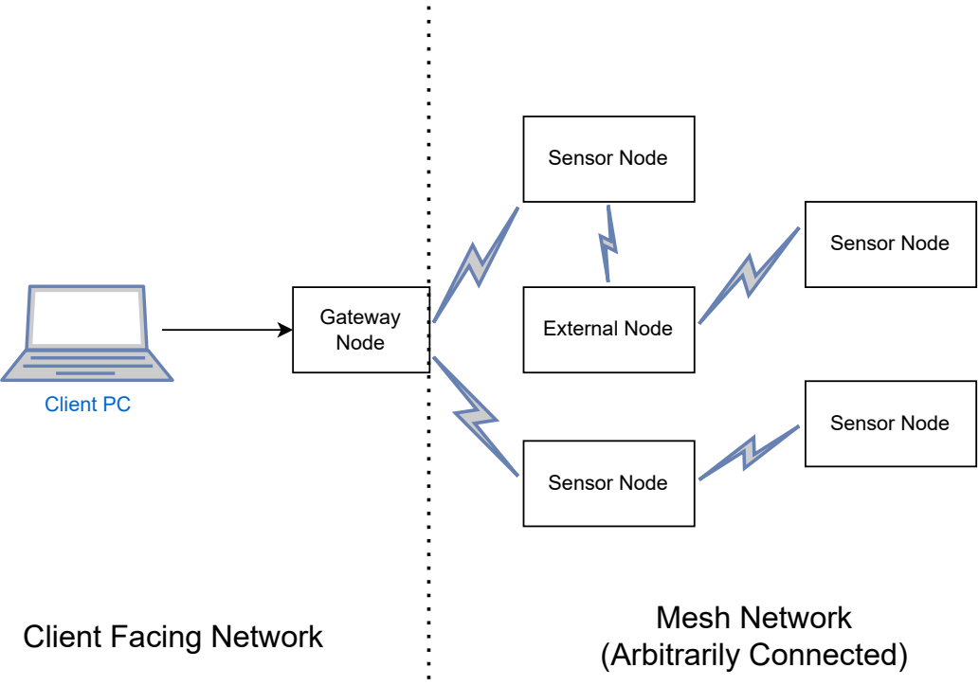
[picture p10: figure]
Gateway Node; Sensor Node; External Node; Client PC; Mesh Network

## (Arbitrarily Connected) Client Facing Network

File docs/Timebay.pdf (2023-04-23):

# Timebay: an Ad-Hoc Distributed System For Student Vehicle Testing

Andrew Ealovega

Abstract—The University of Michigan Dearborn features many student vehicle teams that rely on test data to inform their innovations. Currently, each team has their own dedicated systems for testing, of varying quality and price. This paper introduces Timebay, a system that ergonomically provides testing infrastructure that can be shared across teams. Timebay is a network of sensor nodes that provide both online timing data for optimisation, as well as a reliable network connection to vehicles in motion for debugging and other uses. This is achieved by exploiting the observation that these two domains together create an environment compatible with mesh networking technologies, which can be used to enhance the user experience for both use cases.

I. INTRODUCTION
T
HE University of Michigan Dearborn (UMD) plays host to many competitive student organisations. These organisations challenge students to form cross-functional teams with their peers to approach a common task (such as rocketry, robotics, etc.), before pitting their solution against those of other schools across the country. Two of these teams, UMD-Racing and the Intelligent Systems Club, will be the focus of this paper.
UMD-Racing¹
is UMD’s Formula SAE Combustion team. Their competition has them build, test, and race a formula car over the span of a single school year. As part of their program, UMD-Racing performs extensive testing days to evaluate their work, and practice for competition. These testing days also serve another very important purpose outside of engineering however: driver training. FSAE competitions nearly always feature a kinetic component, where teams actually race their vehicles against each other in various formats. Because these vehicles can be rather challenging to drive, drivers must spend many hours in the vehicle to get used to its handling. The primary measurement of driver skill (although not the sole measurement) is of course lap times, which will become relevant shortly.
The Intelligent Systems Club²
(ISC) is UMD’s general competitive robotics team. While ISC has competed in many kinds of events in the past, they are currently branding themselves as the schools autonomous racing team. Competing in the fledgling Autonomous Karting Series, ISC’s primary project is the creation of a fully autonomous go-kart. Unlike UMD-Racing, ISC’s vehicle does not feature a driver whatsoever, instead featuring a powerful, and networked, onboard computer. Like UMD-Racing, ISC performs testing days to evaluate

1https://umdearbornfsae.weebly.com
2http://www.iscumd.com

performance. Once again, lap times are a useful metric of overall system performance. A challenge unique to ISC has been access to the onboard computer, since it must be headless. The solution to this classically has been to bring a home router to the testing site, as well as batteries to power it.
Recently, both teams have run into issues with their testing. First, UMD-Racing currently does not have any sort of timing system, so driver performances are ranked using a manual stopwatch. This is obviously a rather course metric, which also lacks any sort of contextual data about where on course one driver may be performing better than another. Second, ISC lacks any sort of infrastructure for testing their new Kart. All of the prior stated timing issues also apply here, just with evaluating a model rather than a driver. In addition, the team has been aiming to make their systems more ergonomic compared to past projects, networking included. While the past router solution has worked, carrying around a full size router just for a single connection is rather wasteful. In addition, it suffers if the testing area gets too large for the single router to cover, which is more likely this year with the kart than with less mobile robots of the past.
I propose that both of these issues can be solved together, using a system dubbed Timebay (a combination of the metric time, as well as highbay, the room on campus where the teams meet). To design Timebay, three primary design goals were identified from the prior requirements:
1) Provide granular online lap time data
2) Provide wide ranging network access to the vehicle
3) Be reasonably ergonomic, such that those with little knowledge of IT can still operate the system
Before we can begin to attempt to solve these goals together, we first need to investigate existing systems that solve them separately. To do this, we have identified a representative solution for each goal:
- Goal 1: Sector timing systems
- Goal 2: Mesh networks

II. EXISTING SOLUTIONS

A. Sector Timing

In motor sports, a sector refers to a section of the full circuit. Sector times are thus simply the amount of time it took a driver to pass though a sector’s bounds. This is similar and somewhat interchangeable with the term time splits or just ’splits’. Such a timing system is often complemented by time deltas, which are the differences in time taken between two laps in the same sector. For example, if a driver discovers a better way to enter a turn, their sector time will go down, and their time delta will report the empirical amount of time saved.
These systems are often used to compare two drivers performances, as well as analyse one’s own performance while training. The primary advantage of using a sector timing system over a full course system is the introduction of context to the full lap time, since one can view where time was gained or lost around the course.
Most sector timing systems are implemented using a series of sensors around the course, with some sort of receiver on the car itself. As the car passes a sensor, its time is logged on the car, or alternatively some sort of central computer. An example of such a system is the MoTec BTX and BT2, which is the system UMD-Racing would use without Timebay [1]. These systems are quite expensive, as seen by the (at the time of writing) $790.00 price per transmitter in the MoTec system. Upon interviewing UMD-Racing, they explained that the primary use of a sector timing for their student team would be for online information. This is because they already have advanced sensors for tracking position, but this data must be processed over a period of hours following practice. While training drivers, they could utilise the extra information given by a sector timing system to more scientifically iterate improvements. This makes a system like the above MoTec a difficult proposition, since it’s a system designed for professional racing with many features UMD-Racing would not use. For UMD-Racing, timing data alone would suffice.
B. Mesh Networking

Both teams operate in regions without existing network infrastructure. Thus, when supplying network access to the vehicle, we must utilise ad-hoc networking. One popular approach to ad-hoc networking is mesh networking. Mesh networks, sometimes referred to as wireless mesh networks (WMN), are a network topology where the network is both managed and created by some set of stations. They are highly dynamic, and need to handle network degradation or complete node loss gracefully [2]. Relevant to this work are mesh networks created using WiFi, for which there are two prominent implementations: BATMAN-adv and 802.11s. BATMAN-adv: BATMAN-adv (better approach to mobile ad-hoc networking advanced) is a routing protocol for multihop ad-hoc networks [3]. It operates on OSI layer 2, and is implemented in an in-tree Linux kernel module, which makes it available on any reasonably modern Linux system. BATMAN-adv is rather interesting in that it can run over both wired and wireless networks. To do this, it operates over Linux network devices, ultimately providing a network device (bat0) as its API. This allows BATMAN-adv to be used over rather heterogeneous networks. Of note is that this means BATMAN-adv can be used to allow for multi-hop routing at layer 2 in 802.11 IBSS (ad-hoc) networks, which are normally single hop only.
802.11s: 802.11s is the mesh networking protocol implemented into the 802.11 standard itself [4]. Being an 802.11 extension itself, 802.11s operates on layer 2. This does however mean that, unlike BATMAN-adv, 802.11s only works with devices both running WiFi and with drivers that support mesh mode operation. Linux does have support for 802.11s in its native driver stack, however only a few chip-set drivers actually implement this interface [5]. Unlike BATMAN-adv, 802.11s does have the nice advantage of being usable with non-Linux devices, making it better at handling device heterogeneity.
Little existing works investigate the use of these protocols in vehicular mobility. [6] Found BATMAN was ill suited to robotic teleoperation with its default settings, but could work spottily with some adjustments. In [7], the authors find BATMAN-adv to be more capable of handling mobile scenarios then rival protocols, given a predictive extension. In [8], the authors investigate 802.11s under high speeds. They found applications resistant to jitter could run over the connection, although jitter sensitive connections like voice and video could not.
For ISC’s use case, mobile connections to the vehicle would be highly desirable, but not necessarily required. This is because there are still many use cases where having the vehicle parked somewhere on the circuit with network access would be valuable.

III. DESIGN

The design of Timebay is based around the key observation that goals 1, when implemented using a sector timing system, and 2, when implemented as a mesh network, lead to a physically similar topology (visualised in fig. 1). This naturally occurs because both systems want to be close to the car. The sector system does this for contextual data, and the mesh network does this for coverage. This makes these two solutions naturally complementary. As the car goes around the circuit, it will pass by sensors to read its sector time. If we also add networking to these sensors, then the car can also move its connection to that local sensor node. Further, these sensor nodes will be spread somewhat equally across the track. Given these nodes form a mesh network, the mesh will be able to form around obstacles that would have otherwise blocked a directional signal from a single station (such as the home router ISC uses).
This sensor-mesh approach also conveniently handles part of our third goal, ergonomics. Mesh networks are, by definition, self organising. This means that they avoid many of the intricacies of setting up an AP for an end user since they can just be pre-configured by the creator. These mesh networks will also be more resilient to interference, since they can naturally route around something like a locally strong EMF. This should assist in abstracting away the complexities of networking from the user.
There is an issue with using a mesh network approach however. For either use case, an end user cannot get information out of the the network without also using a mesh compatible machine. This goes against our ergonomic goal. To solve this, we introduce a gateway node, which is simply a node that allows for access to the mesh network without participating in the mesh itself. End users will attach their computers to this node, allowing the mesh network to be abstracted away. To

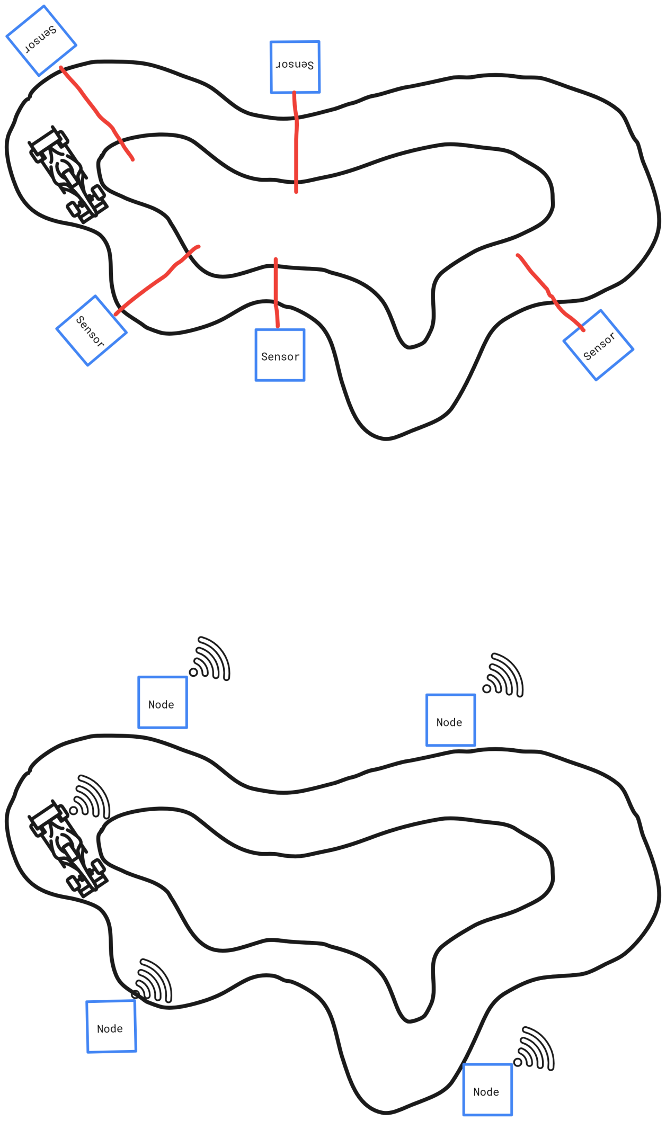
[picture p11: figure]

Fig. 1. A visualisation of the physical similarities between a mesh network and sector timing system

aid in debugging the mesh network from outside, a GUI will be developed that displays sensor node connection status.

A. Components

In summary, Timebay is comprised of:
Sensor Nodes - Nodes that handle both detection of a passing vehicle and organisation of the mesh network. Timebay should support 1-many sensor nodes in a network, where each sensor node is allocated a unique identifier. These nodes are fully wireless and battery powered to ease setup.

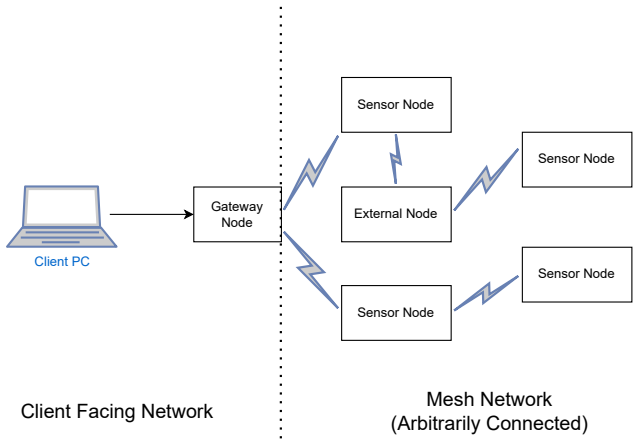
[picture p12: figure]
Gateway Node; Sensor Node; External Node; Client PC; Mesh Network (Arbitrarily Connected) Client Facing Network

Fig. 2. High level network topology

Gateway Node - A node that serves as the single entry point to the mesh, and Timebay as a whole. This node should have two network interfaces. One participates in the mesh, and the other allows for access to the mesh (via NAT, bridging or otherwise). Any centralised components of Timebay should also run on this server, such as network management utilities or databases.
External Nodes - Guests that participate in the mesh, but are not sensor nodes. These nodes use the mesh simply for its network access to the gateway or other external nodes. An example of an external node would be ISC’s onboard PC. Clients - End user computers that have no mesh compatibility. These are off the shelf laptops that may be running one of many OSes. Clients should connect to the external network interface on the gateway node to access all network resources. A cross-platform GUI application will be provided that will handle access to all of Timebay’s timing functions.

IV. IMPLEMENTATION

A. Hardware
Nodes - Our node implementation uses the Libre Compute Le Potato single board computer. This is a Raspi3 like board that has an 800Mhz processor, 2Gb RAM, and 1/100 Ethernet. To allow for wireless connectivity, we use ALFA AWUS036ACM (mt7612u chipset) wireless adapters. Sensor Nodes - Vehicle detection will be preformed using a TF-Luna laser distance sensor. This sensor will be used like a line break sensor, detecting the vehicle when an object is detected some threshold closer than the zero point.
Gateway Node - Clients will connect to the gateway node using it’s Ethernet port.
B. Network
The first key decision required for Timebays network implementation is a choice of physical layer protocol. Three main protocols were considered during this process.
- WiFi - High bandwidth commodity standard
- Bluetooth - Low bandwidth, low power


Fig. 3. A sensor node

- Zigbee - Lowest bandwidth, commonly used in mesh networks
Overall, Zigbee is likely the most fitting protocol, since it allows for using very low power devices for sensor nodes, and natively supports mesh networks. For Timebays use case however, Zigbee’s middling 250Kbps bandwidth is simply too slow for some of the more intense activities ISC may perform [9]. For example, creating an FPV video setup would require bandwidth well into the tens of megabits, which only WiFi supplies. For this reason, WiFi was chosen as the wireless protocol.
For our layer 2 mesh protocol, Timebay implements both a BATMAN-adv and 802.11s option. This is done due to the lack of conclusive evidence supporting either protocol as being definitively superior in the context of mobility. Additionally, little documentation exists regarding the current state of each project, or their associated hardware quirks.
All nodes get dynamic IPs in the 192.168.0.0/24 subnet, allocated by a DHCP server on the gateway node. The gateway node itself has the static IP 192.168.0.1, to allow for connections to centralized resources. DHCP was chosen over static IPs to allow for scaling the number of external nodes in mesh without requiring the user to maintain a record of allocated addresses.
To allow for clients to connect to the mesh network, the gateway node creates a Linux bridge interface between its Ethernet port and its mesh interface. The gateway node is only accessed via the IP address on the bridge, so clients connecting to the mesh can access any other mesh node as if they themselves were on the mesh. This also allows for clients to receive DHCP addresses, as DHCP will flow over the bridge.
C. BATMAN-adv Configuration
BATMAN-adv is by default not very mobile friendly, as discussed in [6]. Borrowing from that work, we will configure BATMAN to send OGM every 50ms. The goal of this is to minimize the time it takes for the mesh to reconfigure

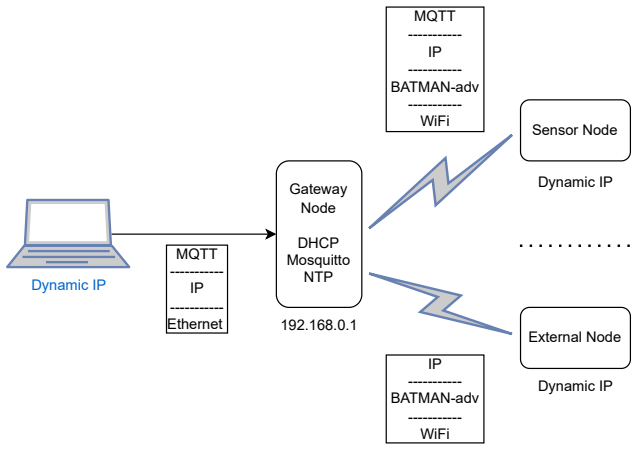
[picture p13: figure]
Gateway Node; DHCP Mosquitto NTP Dynamic IP; MQTT ----------- IP ----------- Ethernet; Sensor Node; MQTT ----------- IP ----------- BATMAN-adv ----------- WiFi; External Node; IP ----------- BATMAN-adv ----------- WiFi; Dynamic IP

Fig. 4. Timebay network implementation

routes, critical to ensure dead nodes are routed around and mobile external nodes quickly change mesh links. To aid in this, OGM aggregation is also disabled, as recommended by the BATMAN-adv docs [10]. Both of these configurations will likely lower throughput, but should hopefully improve persistence in exchange. Following the results of [11], we will be using BATMAN IV over V.

D. Sensor Node Communication
All data related to the timing features of Timebay are broadcast across the network using MQTT. MQTT was chosen in this case not for its low bandwidth requirements (although this is nice), but rather its convenient pub-sub architecture which naturally mixes well with our highly dynamic network topology. The MQTT broker for Timebay is hosted on the gateway node.
The following topics are used:
/connect - Published to by nodes when they connect or reconnect to the broker. Nodes are allowed to publish to this topic when already connected, as a sort of heartbeat. /disconnect - Published to by nodes when they disconnect from the broker, via LWT.
/zero - Causes all sensor nodes to zero their sensors. /sensors/detection - Published to when a node detects a passing vehicle.
E. Time
As the name would suggest, time is rather important in Timebay. When sensor nodes send their data to the client to create sector times, we need to ensure that the client has an accurate estimation of the time that detection actually occurs. There are two ways to approach this problem:
1) Timestamp when we receive sensor detections on the client
2) Timestamp before we send the detection over MQTT, on the sensor node

When evaluating this issue, it’s important to remember that what we need to combat here is not the offset between the client and sensor nodes, but rather the offset between each of the sensor nodes with respect to other sensor nodes. This is because lap times on the client are stored as absolute time values of the start and end of the sector. If one node’s time has error from either approach, and that error is different than the error of any other node (what I call offset), the lap time will be inaccurate. From this view, it should be obvious that approach 1 is not viable. This is because every node on the network will naturally have different network latencies to the client, since synchronising latencies is not the goal of a mesh network. For approach 2, network latencies are not a direct issue. Instead, what adds offset is clock desyncronisation (or rather, clock offset as the term is normally used). Because the SBC’s used for sensor nodes do not have a RTC, this necessitates the use of a clock synchronisation solution.
Clock synchronisation in WSN is a well studied area [12]
[13] [14] [15]. While these approaches do show promise, unfortunately few have open implementations, especially on Linux. Because we lack the resources to implement one of these protocols ourselves, we decide to simply use NTP, the traditional time synchronisation protocol on the Internet. As discussed in [12], an issue with NTP in mesh networks is the potential for asymmetrical latencies in RTTs. To help curb this issue, we chose Chrony as our NTP implementation. Chrony uniquely supports estimating delay asymmetry in its connections, going beyond the requirements of NTP itself [16]. Clock synchronisation in Timebay is implemented by synchronising all nodes to the gateway node, since that will be the node that is always present. Because we only care about reducing the offsets between sensor nodes, it does not matter that the gateway node itself may be desyncronised. Accordingly, Chrony is configured to use its local mode, which will serve NTP using the local clock as if it was synchronised. We also declare the servers stratum as 1, since we want all nodes to see the gateway as authoritative. Each sensor node runs Chrony configured to only access the gateway’s server, forcing the clock to step if error is greater than 1 second. This is done in hope of forcing fast convergence on system setup, since all nodes will be greatly desynced on boot due to the lack of a RTC.
F. Sensor Node Detection

The sensor node vehicle detection code is implemented as a Rust executable. Using the Tokio reactor, it polls over both an MQTT channel and the laser rangefinder concurrently, zeroing the sensor on MQTT command or sending a detection report to MQTT respectfully.
When detections have not occurred for some period of time (currently 3s), sensor nodes will send a heartbeat message on /connect. This is done not to tell if a node is disconnected, as MQTT does that with its own heartbeats, but rather to allow for late-joining clients to discover sensor nodes without requiring those nodes to have a detection.
G. Deployment
All Timebay nodes are implemented as Docker containers to help abstract over hardware heterogeneity, as well as to ease the difficulty of adding new sensor nodes. These containers are set up to boot on board restart via cronjob.
Because we need to access wireless interfaces from the container, we disable most virtualisation features of Docker. This involves running the container as privileged, using host networking, adding SYS TIME capability (required for NTP), and mounting /dev/.
To ease updating potentially many nodes, we set up a sort of ’OTA’ update system. When a node boots, we configure its Ethernet port with DHCP if a carrier is available. In its bringup script, we fetch the Timebay repo’s upstream. If we have a carrier on eth0 and the remote is ahead of HEAD, then we pull the remote and rebuild the docker container. This means that to update many nodes, one simply needs to plug them all into a switch and supply power.
The general boot process for sensor nodes is:
1) Run bash script that git pulls Timebay, and rebuilds the docker container if new changes were pulled
2) Run docker container
3) Find a mesh/IBSS compatible interface by scraping iw output
4) Use iw to set the device to IBSS/Mesh mode
5) If using BATMAN-adv, setup bat0 interface
6) Start dhcpcd to get IP address
7) Start sensor node executable
H. GUI
The client GUI application is also implemented in Rust, and utilises shared components with the sensor node. The GUI implements all of the actual application logic for sector timing, aggregating data collected from the MQTT broker. Sectors are defined by pairs of nodes starting at the lowest node id and pairing until the last node, which is paired with the initial node id. Each sector begins timing at the end trigger of the last sector, updating the GUI as the course is completed.
If the car skips a node, the time spent in the sector is simply rolled into the next sector, and the skipped sector is marked invalid. This transparently handles nodes disconnecting, since they will simply be skipped. The alternative would be to invalidate the sector eagerly when the node disconnects but before the car passes it, but this idea was discarded as it complicates the logic of the node coming back online. By treating disconnected nodes as if they were skipped, we optimistically give the node a chance to reconnect with the network without any sort of special logic.
Should the nodes clocks become desynced, it is possible for the GUI to detect the detection timestamps going back in time. If this occurs, the current sector is marked as invalid. When a lap is completed, the GUI calculates the complete lap time and moves the splits to one side of the screen, and then displays the time deltas with respect to the prior lap. Also included in the GUI is a display of all currently connected nodes, as well as a button to zero the sensors. Nodes will display as connected as soon as they send a message


Fig. 5. Timebay’s GUI connected to a single sensor node

to /connect, and will show as disconnected 10 seconds after disconnecting, since we have configured a 10s TTL.
In an attempt to make this GUI as cross platform as possible, it is actually implemented in the terminal, making it a TUI. This avoids linking with platform specific GUI libraries, increasing the chance of the GUI remaining compatible on future, unknown OS versions.
I. Ergonomics
Timebay’s third goal, ergonomics, is primarily achieved by designing the network to be as self operational as possible. For example, all mesh networking is abstracted away by the gateway node. If a node disconnects, one simply needs to wait for it to re-mesh, since the GUI will automatically handle how that addition or reduction of a node will impact lap times. If the layout must be changed, all the user must do is press the zero sensors button in the GUI and the system will be operational again. Mobile batteries are used to power the nodes as opposed to LiPos to allow for easy recharging of nodes by non electrical members.
In addition to these and many more design choices, we make a point to supply ample documentation of the system. This is important, since the student teams have very high turnover, and organisational knowledge around tools is very volatile. In particular, instructions to replicate the current implementation are provided, as well instructions for operation, troubleshooting, and development. To ensure these are not lost while the hardware remains in use, Timebay is open sourced via a GitHub repository³
V. EVALUATION
A. Startup time
First, we will evaluate the startup time in optimal conditions. To measure this, we set up three sensor nodes in a 3m circle around the gateway node attached to a client. A timer is started on the computer, then all nodes are turned on. With the GUI open, we wait until all nodes are displayed in the connected nodes table. The results are shown in Fig. 6. Note that this includes the time for:
1) Booting Linux

3https://github.com/andyblarblar/timebay

Trial (BATMAN-adv) | Time Till complete
1 | 3:30
2 | 3:55
3 | 3:44
4 | 4:21
5 | 3:44
Trial (802.11s) | Time Till complete
1 | 3:11
2 | 3:20
3 | 3:25
4 | 3:20
5 | 3:24

Fig. 6. Timebay startup times

2) Starting Docker
3) Connecting to mesh
4) Getting IP over DHCP
5) Connecting to MQTT
The average startup time was 3:51 for BATMAN, and 3:20 for 802.11s. Upon investigating the boot logs, it appears that approximately 2:40 of this boot time is spent booting the host OS. This is likely due to a misconfigured service. Because both protocols use the same Docker container, the consistently faster boot times on 802.11s is likely due to properties of its mesh. In particular, DHCP is a likely candidate for this lost time. As we will see later, BATMAN-adv has very large packet loss. DHCP requests addresses using a UDP broadcast. Given this best effort approach, dhcpcd’s exponential back-off on failure, and the large packet loss, DHCP can take quite a while to gain an address in BATMAN-adv meshes. This was verified by Wireshark analysis, where DHCP requests could be seen leaving the node but not receiving a response. This could also explain the greater variance shown in the BATMAN-adv results.
B. Clock Synchronisation
Next, we will verify that nodes are being synchronised. This test can be seen as a validation of goal 1, since the sector timing logic works as expected, leaving only the clock synchronisation as a potential issue. This is done by placing two sensor nodes next to one another, then dropping a piece of cardboard in front of them. Because the nodes should trigger at roughly the same time, we can compare the GUI’s received timestamps to find the offset of the clocks, and thus the error our timing system will see per sector. This process is begun first by rebooting the nodes to force a fresh NTP state, then collecting five samples when the nodes appear in the GUI. The results of this experiment are displayed in fig. 7. Note that stamps include only the nanoseconds component, as no readings had greater than a second of error. Offsets are rounded to the ms as our testing apparatus does not have ns accuracy. These results show us a few things. First, our aggressive stepping of clocks until second accuracy is achieved has achieved its goal of getting the clocks reasonably synchronised within a short period of time. Second, even with very little time to converge, both protocols have an acceptable level of error.

BAT | Node 1 stamp | Node 2 stamp | Offset
1 | 133668199ns | 158070397ns | 24ms
2 | 568918805ns | 570767970ns | 2ms
3 | 728301891ns | 746114176ns | 18ms
4 | 503307445ns | 501268735ns | 2ms
5 | 331404650ns | 335236888ns | 4ms
802.11s | Node 1 stamp | Node 2 stamp | Offset
1 | 710317045ns | 758237086ns | 8ms
2 | 321956813ns | 334979791ns | 1ms
3 | 409371012ns | 430514388ns | 2ms
4 | 328401762ns | 355385103ns | 3ms
5 | 716304263ns | 731996424ns | 2ms

Fig. 7. Timebay clock synchronisation offsets

802.11s especially, with all measurements under 10ms. While this advantage could be from NTP having issues contending with BATMAN’s packet loss, our testing apparatus has too much potential for procedural error for this to be conclusive.

C. Packet Loss

While performing other tests, many were failing to pass due to massive packet loss. To investigate this issue further, we test the packet loss under various setups to find any patterns. For all of these configurations, the client is connected to the gateway node and SSHs into it. From the gateway node, we use ubuntu’s ping utility to test the packet loss to one of the sensor nodes until 150 sequences are reported. For each configuration, we repeat this test for 1, 2, and 3 connected sensor nodes. The results of these tests are shown in fig. 8.
First, we test BATMAN-adv with 50ms OGM, which was the configuration initially proposed. As shown in fig. 8, there is a massive jump in packet loss when a second node is added, with a further increase with a third. To investigate if this issue was caused by our aggressive OGM rate, we run the test again with 500ms OGMs. Once again, packet loss jumps massively when a second and then third node are added, although less so than with the 50ms OGM. To ensure this isn’t a fundamental issue with our system, we finally repeat the test with 802.11s. These results are a little hard to view in the chart, since there is literally no packet loss, regardless of node count. This result was quite surprising, since other literature on BATMAN-adv does not document packet loss issues. The packet loss only begins once IP data begins to be sent, not when the IBSS forms. Because of this, its possible this is a misconfiguration of BATMAN-adv, although we use all default settings aside from OGM rate, which makes this unlikely.
D. Throughput In Motion

Finally, we will evaluate throughput of the mesh with a vehicle in motion. This can be seen as a validation of goal 2. Unfortunately, neither teams vehicle was available for testing. As a stand in, a collaborator’s 2023 Ford Maverick XLT 2.0L EcoBoost AWD will serve as our vehicle. To ensure fair results, we have a laptop held in the bed of the truck to prevent the body from blocking signals. This is important because both

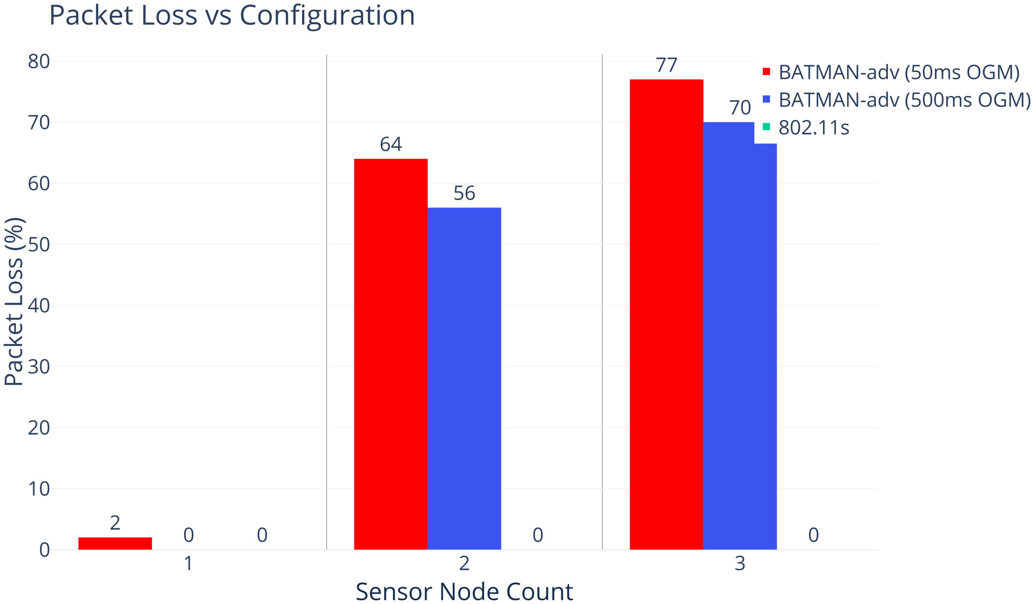
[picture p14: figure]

Fig. 8. Packet loss under various configurations


Fig. 9. Testing setup for throughput tests

student vehicles allow for unobstructed antennas. Testing was done on a parking lot on campus, with 3 sensor nodes and the gateway node spread throughout. The distribution of these nodes is displayed in fig. 9. The laptop held in the bed will be simulating the onboard PC of ISC, connected to the mesh as an external node. We will only perform these tests using 802.11s, since BATMAN-adv’s packet loss was too high to perform the test with 5 total nodes. For each test, the vehicle will drive the perimeter of the lot while iperf3 runs a TCP bandwidth test of the network between a client connected to the gateway and the external node on the vehicle. Pings will run for all tests to collect aggregate latency measurements. The results of these tests can be seen in fig. 10.
As can be easily observed, Timebay has very large amounts of jitter while in motion. This was not unexpected, and tracks


Fig. 10. Throughput of the mesh with vehicle in motion

with the results of [8]. This can be seen in the latency results, where we see a minimum RTT of 1.3ms, a max of 1800ms, an average of 68ms, and a standard deviation of 123ms. From the period of around 15s - 34s, a large drop in throughput, or even the connection, can be seen in all runs. This is due to a large block of parked cars in the lot fully obscuring the vehicle from all nodes. This gives us the opportunity to observe the mesh reforming under motion, which it does very smoothly shortly after the vehicle emerges at approx. 35s. Note that because of this, 35s onwards is the most representative of an average use case, as the vehicle is in motion and in range of at least one node. This range still shows large variance in throughput, ranging from 2Mbps to 20Mbps depending on the run. Overall, these results show that Timebay is not suitable for real time data transfer from an external node, such as for teleoperation. It is, however, capable of transferring data at reasonable speeds (faster than alternative wireless standards) in jitter durable applications. An example of this could be viewing ROS topics from the external node in Rviz, where latency is less of a concern than persistence and reasonably fast speeds.

It is worth pointing out that the above results apply to a vehicle in motion only. While stationary, Timebay can maintain consistently high speeds, sometimes even pushing up against the bandwidth of the 1/100 gateway link. This applies to both the vehicle while stationary, as well as other possible uses of external nodes, such as remote terminals around the circuit.

E. BATMAN-adv vs. 802.11s

As can be seen throughout the evaluation, the choice of BATMAN-adv vs. 802.11s significantly changes the behavior of Timebay. Of course, Timebay can only use one of these protocols at a time, so it is worthwhile defining a default.

A running theme throughout the creation of Timebay was the mesh protocols acting significantly differently given different hardware. Initially, the system used wireless adapters in the rt2800 chip-set family. While using these drivers, 802.11s was unable to bridge with the Ethernet port on the gateway, preventing the use of 802.11s in Timebay. When the project moved to adapters that used the Linux mt7x drivers for unrelated reasons, 802.11s was fully operational. This poses a significant issue for recommending a protocol, since reproductions of Timebay in the future may outright not function if chip-sets change even in vetted adapters. Unfortunately, BATMAN-adv was nearly unusable with multiple nodes in either setup due to its massive packet loss. However, it was capable of bridging even with the rt2800 adapter. Awkwardly, this leaves BATMAN-adv with a niche where it is still technically better than 802.11s, by virtue of running at all.

Overall then, 802.11s is currently far and away the better implemented protocol on Linux, so long as you have an adapter with the correct chip-set. If you don’t, then BATMAN-adv can be used as a fallback, although it shouldn’t be used with more than one sensor node.

VI. CONCLUSION

A. Limitations
1) Security: Timebay lacks any security whatsoever. This means that anyone is capable of connecting to the mesh and accessing its resources. Realistically, this primarily makes external nodes like ISC’s PC vulnerable to external connections if not secured. For a more professional application, this would also make the system vulnerable to passive and active attacks on the sensor detection times over MQTT. This could be an issue if say, a formula team is practicing around competitors. For the intended use case, I do not consider this a large issue, since the onboard PC is already secured and messing with lap times is harmless. The system should be amendable to hardening many of its interfaces, such as requiring a password for MQTT and encrypting WiFi using 802.11s’s SAE [5].
2) SBCs: Timebay, by its reliance on Linux, requires the use of SBCs that are likely far more powerful than needed. This reliance comes from a few sources:
1) Mesh Implimentations
2) Current sensor node implementation codebase
3) NTP
While 2 could be programmed away, 1 and 3 are far more difficult. Both mesh algorithms and clock synchronisation suffer from a lot of theoretical algorithms but a lack of implementations. Even when implementations are available, they are often for a particular embedded OS, lowering the odds of the other system also being available. Should this issue be resolved, Timebay could likely be implemented using a microcontroller like the ESP32 as the sensor node platform, although throughput would need to be re-verified.
B. Future Work
Timebay is still a very young system, and has many areas that could be significantly improved given future work.
1) 802.11s Parameters: All tests were performed using default 802.11s parameters, largely due to a lack of time for iteration. These parameters, especially those controlling the HWMP, can likely be significantly optimised for the moving vehicle scenario. 802.11s also natively supports the concept of gateway nodes, something that we do not utilise in this work.
C. WiFi
All mesh configurations currently use 2.4ghz channel 5 with HT40+ for their underlying WiFi connections. Channel 5 was chosen after a site survey of campus found it to be the least congested. Even with this choice, the 2.4ghz spectrum is very polluted from various industrial machines around campus. Future work should investigate both the use of the 5ghz spectrum as well as various channel widths to potentially increase throughput and other metrics.
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

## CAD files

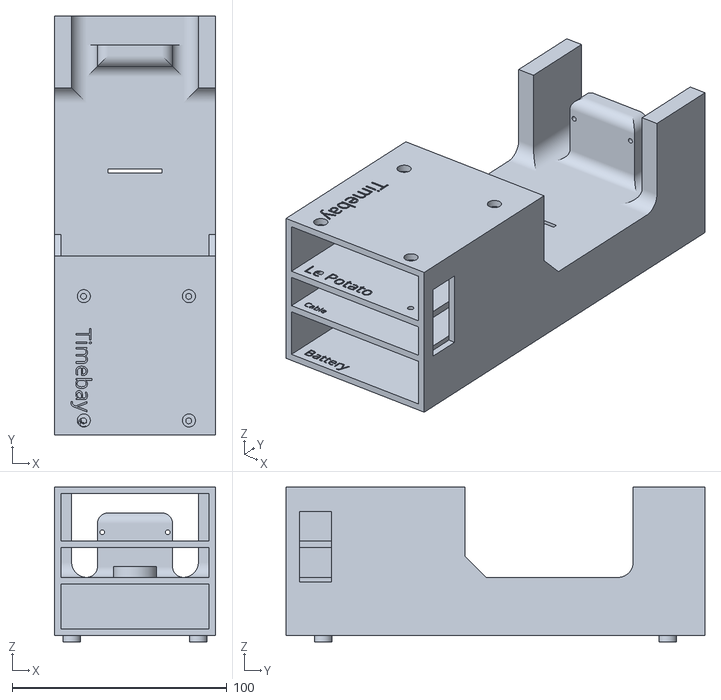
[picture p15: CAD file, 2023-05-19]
CAD/Le Box.stl
75.0 x 195.0 x 72.0

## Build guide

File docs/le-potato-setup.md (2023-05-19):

# Le-Potato setup



This is a guide to setting up all nodes using [Le Potatoes](https://libre.computer/products/aml-s905x-cc/).

> This guide will be assuming ubuntu 22.04 server, as described in the libre compute docs

## OS setup

1. When setting up 22.04 server, set eth0 to use DHCP in the cloud init config (before flashing)
2. Flash SD card as described in their docs
3. Connect Potato to Ethernet 
4. Install Docker
5. Add user to docker group
6. reboot
7. Clone timebay
8. Add a cronjob to enable uarta with: `ltdo enable uarta` on boot (must be in superusers crontab)
9. Delete /usr/lib/systemd/network/80-adhoc (If this is not done, then the wireless adapter will be dropped from bat0 if BATMAN is used)
10. Add a cronjob to run scripts/run_sensor_node.bash Node_ID or scripts/run_gateway_node.bash depending on node type on boot
    1. Ensure this node id is unique, or else the system will not work correctly
11. If setting up a gateway node, apply the kernel parameters:
     ```
     net.bridge.bridge-nf-call-iptables=0
     net.bridge.bridge-nf-call-ip6tables=0
     net.bridge.bridge-nf-call-arptables=0
     ``` 
    This can be done by adding a rule to sysctl.d, and adding a udev rule to load that rule when br_netfilters is loaded.
12. Finally, reboot with an ethernet cable connected to an uplink, and wait 10 minutes or so for the docker container to complete its first
    build. The potato is now ready!

## Box
If you want a box to hold the node in use, see the resources in [the CAD folder](../CAD).

## Running
To run the node after the above is setup:
1. Connect the Wi-Fi adapter to a usb port
2. Connect the TF-Luna to either GPIO or via a usb to UART converter (Timebay will select whichever is used)
3. Before powering on, ensure there is an object within 12m in front of the laser. If not, the laser will obtain a zero of 0, and not detect anything
   1. If this is not done correctly or the course is changed, simply correct the issue and zero the sensor via the GUI
4. Connect the potato to a power source, and wait ~3 minutes for it to boot and mesh

## Updating
To update the potato to the latest Timebay version:
1. Turn on the node with an ethernet cable connected
2. If Timebay on the node is not in sync with origin, then it will pull the changes and rebuild the correct Docker container
   1. This can take ~10 minutes, so go make a sandwich or something
3. You are now up-to-date!

## Troubleshooting
- If the blue LED on the potato is not blinking, then the board has died (it is solid when booting however)
  - This indicates a power issue, so you'll need to make sure your source has >1A of current @ 5v. USB cables have been an issue for me before, so check that too.
- To debug most networking issues, just connect the Potato to a monitor. Docker logs can display the sensor node executables output.
- If the gateway node has a working layer 2 but not layer 3, (IE wireshark shows ARP but not pings), ensure the kernel parameters were actually applied.
- If the sensors appear to be ignoring the vehicle, ensure they both have an object within 10m, and that object is > 20cm away from the vehicle.

### Notes
- If you want to create many sensor nodes, it is possible to set one node up
, then copy that sd card to a file with `dd`, then copy that file back to another sd card with `dd`
. Just make sure to change the node id.
- Sensors connected to uarta will appear on /dev/ttyAML6. This interface does not have a udev id, so you'll just need to hardcode the path.
- Potatoes seem to be quite picky with power, although not as much as a pi. 1.5A mobile batteries and a quality usb cable seem to work for me, although it can still die if plugging in a keyboard.
- If you are using the reference image (not public atm) it is currently setup using the above guidelines. 
  - Username is ubuntu, and password is timebay

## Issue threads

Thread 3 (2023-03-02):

wireless interface on nodes randomly stops working

andyblarblar, 2023-03-02:
I think the interface may be entering a low power mode. One time I'm pretty sure running ip a woke it up, so perhaps we need a cronjob that just runs ip a once and a while

andyblarblar, 2023-03-03:
Doesn't seem to be a power savings thing, since ip a doesnt actually break it. The issue seems to be more likely over time, and only appears after running sensor -> stopping -> running sensor again. Running the sensor node back to back will always yeild some conenction issues breifly. Layer 2 comms are up this whole time, so think the mesh is fine, and its likely a routing issue.

A promenent suspect for me is the ip autoconfig address sometimes on bat0 on the sensor node. Not sure how to disable this, because we need DHCP on.

andyblarblar, 2023-03-10:
In IRL testing, it seems that the sensor nodes don't actually poll for DHCP, may be releated

andyblarblar, 2023-04-08:
this was caused by networkd rules bringing up the wireless adapter as LL, casuing bat0 to drop the interface

Closed 2023-04-08.

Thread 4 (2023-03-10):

sensor nodes do not actually disconnect from MQTT when they lose connection

andyblarblar, 2023-03-10:
This may not be a huge deal, since sensor nodes are not designed to randomly lose connection, but it may be worth doing for better debugging in the GUI. Need to look into if there is an MQTT setting for how long it considers a node gone for

andyblarblar, 2023-03-10:
attempted to fix in 1a2d3fabf076e6eb2a958c91f14244ac5bce2569, need to test

Closed 2023-04-15.

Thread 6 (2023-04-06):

batman removes interface when wifi gets address

andyblarblar, 2023-04-06:
BATMAN seems to be removing the wireless interface when that interface gets a LL address from networkd on the sensor node. This seems to be the cause of it not connecting.

andyblarblar, 2023-04-06:
Attempting to just edit /usr/lib/systemd/network/80-adhoc-wifi to remove the LL = true

andyblarblar, 2023-04-06:
This works! Will prob need to add to the potato we make a gateway as well

Closed 2023-04-06.

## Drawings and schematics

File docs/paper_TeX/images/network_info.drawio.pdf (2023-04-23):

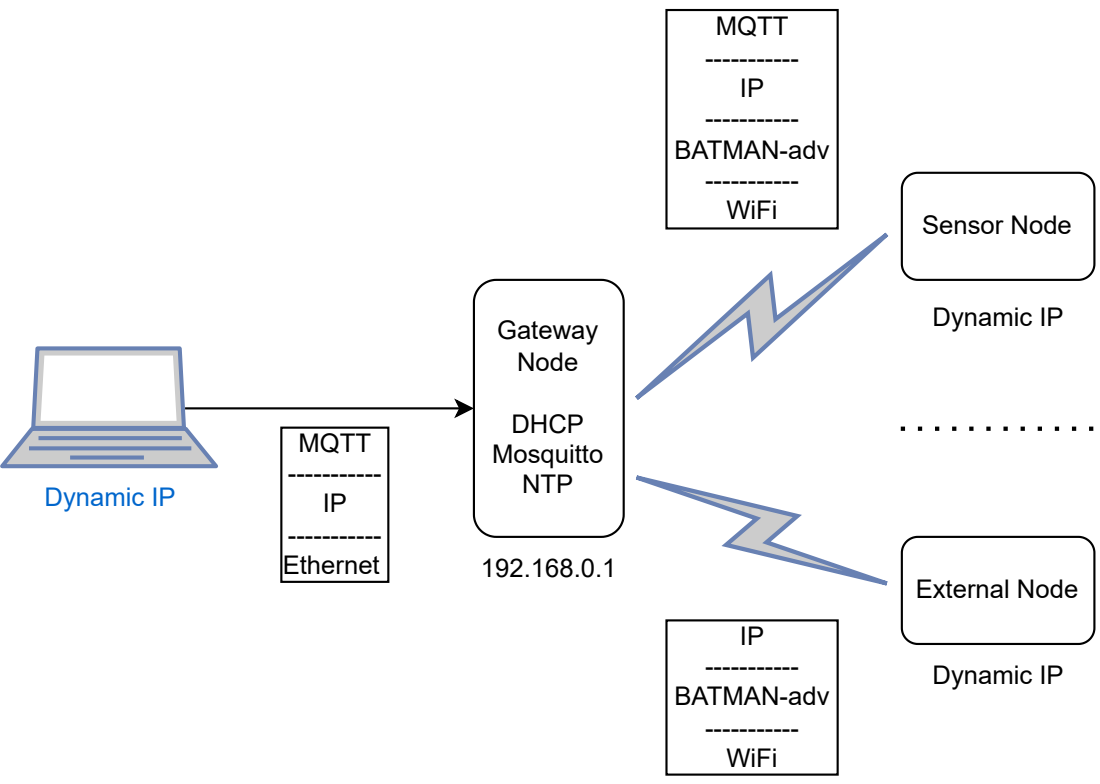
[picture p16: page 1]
Gateway Node; DHCP Mosquitto; MQTT ----------- IP ----------- Ethernet; Sensor Node; MQTT ----------- IP ----------- BATMAN-adv ----------- WiFi; External Node; IP ----------- BATMAN-adv ----------- WiFi; Dynamic IP

NTP Dynamic IP

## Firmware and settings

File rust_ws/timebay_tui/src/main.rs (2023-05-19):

mod app;
mod backend;
mod error;
mod mqtt;
mod mqttsub;
mod splits;

use crate::app::{App, AppMessage};
use crate::backend::SharedState;
use cursive::menu::Tree;
use cursive::traits::*;
use cursive::views::Dialog;
use cursive::Cursive;
use flexi_logger::filter::LogLineWriter;
use flexi_logger::{DeferredNow, FileSpec, Logger};
use log::Record;
use std::ops::Deref;
use std::sync::{Arc, Mutex};

fn main() {
    // Broker host can be passed via CLI
    let host: Vec<_> = std::env::args().take(2).collect();

    let mut siv = cursive::default();
    siv.set_autohide_menu(false);

    // Add a way to view logs
    // TODO replace with default logger once https://github.com/gyscos/cursive/pull/719 is merged
    Logger::try_with_env_or_str("trace")
        .expect("Could not create Logger from environment :(")
        .log_to_file_and_writer(
            FileSpec::default().directory("timebay_tui_logs"),
            cursive_flexi_logger_view::cursive_flexi_logger(&siv),
        )
        .filter(Box::new(PhaoMqttFilter {}))
        .format(flexi_logger::colored_detailed_format)
        .start()
        .expect("failed to initialize logger!");

    // Communications between gui and background thread
    let (backend_tx, backend_rx) = crossfire::mpsc::bounded_tx_blocking_rx_future(10);
    let cb_sink = siv.cb_sink().clone();
    let app = App::new();

    siv.add_layer(app.view());

    // We need to share app between threads using user data, since it must be send
    let shared = Arc::new(Mutex::new(SharedState { app, backend_tx }));
    siv.set_user_data(shared.clone());

    let zero_sensors = |s: &mut Cursive| {
        // Because backend handles this message, if we aren't connected nothing will happen
        let tx = s.user_data::<Arc<Mutex<SharedState>>>().unwrap();
        let tx = tx.lock().unwrap();
        while tx.backend_tx.send(AppMessage::SendZero).is_err() {}
    };

    siv.add_global_callback('q', cursive::Cursive::quit);
    siv.add_global_callback(
        '~',
        cursive_flexi_logger_view::toggle_flexi_logger_debug_console,
    );
    siv.add_global_callback('z', zero_sensors);

    // Setup top menubar, since the app only gives the body
    siv.menubar()
        .add_subtree(
            "Actions",
            Tree::new().with(|tree| tree.add_leaf("Zero Sensors", zero_sensors)),
        )
        .add_subtree(
            "Help",
            Tree::new().with(|tree| {
                tree.add_leaf("Controls", |s| {
                    s.add_layer(Dialog::info(
                        "Press Q to quit, ~ for debug logs, z to zero sensors",
                    ))
                })
            }),
        );

    // Because we use an Elm like model, this background thread will receive messages from the gui,
    // act on them, and then edit the whole gui (likely a re-render, though not eccentrically)
    std::thread::spawn(move || {
        backend::backend_thread(
            shared,
            host.get(1)
                .unwrap_or(&String::from("localhost"))
                .deref()
                .to_string(),
            cb_sink,
            backend_rx,
        )
    });

    siv.run();
}

struct PhaoMqttFilter {}

impl flexi_logger::filter::LogLineFilter for PhaoMqttFilter {
    fn write(
        &self,
        now: &mut DeferredNow,
        record: &Record,
        log_line_writer: &dyn LogLineWriter,
    ) -> std::io::Result<()> {
        if !record.target().contains("paho") && !record.target().contains("view") {
            log_line_writer.write(now, record)
        } else {
            Ok(())
        }
    }
}

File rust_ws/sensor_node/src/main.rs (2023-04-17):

mod application;
mod dist_sensor;
mod error;
mod handlers;
mod mqtt;
mod sensor_connection;

use crate::application::ApplicationContext;
use crate::handlers::{handle_mqtt_msg, handle_trigger};
use crate::mqtt::MqttClient;
use log::LevelFilter::Trace;
use simplelog::{ColorChoice, CombinedLogger, TerminalMode};
use std::time::Duration;
use tokio::join;

#[tokio::main]
async fn main() {
    CombinedLogger::init(vec![simplelog::TermLogger::new(
        Trace,
        simplelog::ConfigBuilder::default()
            .add_filter_ignore_str("paho_mqtt")
            .build(),
        TerminalMode::Mixed,
        ColorChoice::Auto,
    )])
    .unwrap();

    log::info!("Waiting for mqtt and sensor to connect...");

    let (sensor, mut client) = {
        // Get broker and node id from env vars
        let node_id = std::env::var("NODE_ID")
            .unwrap_or_else(|_| "1".to_string())
            .parse()
            .unwrap();
        let server_host = std::env::var("BROKER_HOST").unwrap_or_else(|_| "localhost".to_string());

        log::info!(
            "Using a client id {} and broker ip {}",
            node_id,
            server_host
        );

        let sensor_fut = sensor_connection::create_sensor();

        // Future that keeps polling until we connect to mqtt
        let client_fut = async {
            loop {
                let res =
                    MqttClient::connect(node_id, &format!("mqtt://{}:1883", &server_host)).await;
                if let Ok(conn) = res {
                    log::info!("Successfully connected to broker");
                    break conn;
                } else if let Err(err) = res {
                    log::error!("Timed out connecting to broker. Err {}", err);
                    // Prevent spam if connect exits early because of lack of IP
                    tokio::time::sleep(Duration::from_secs(2)).await;
                }
            }
        };
        join!(sensor_fut, client_fut)
    };
    log::info!("Sensor and mqtt both ready!");

    // Zero sensor
    let mut app = ApplicationContext::new(sensor, 10_000, 200);

    while let Err(err) = app.zero().await {
        log::error!("Failed to zero sensor with: {:?}", err);
    }

    let mut disconnected = false;
    loop {
        // Attempt reconnect on disconnect
        if disconnected {
            log::error!("Disconnected from broker!");
            client.reconnect().await;
            log::info!("Reconnected to broker!");
            disconnected = false;
        }

        // Send connected messages as a sort of heartbeat, allowing for late connecting clients to discover us
        let res = client.pub_connected_msg().await;
        if res.is_err() {
            disconnected = true;
            log::error!("Failed connect heartbeat with: {}", res.unwrap_err());
            continue;
        }

        let rcv_fut = client.recv_mqtt_msg();
        let trg_fut = app.wait_for_trigger();
        let timeout = tokio::time::sleep(Duration::from_secs(3));

        // Accept new messages and wait for sensor concurrently (branches are mutually exclusive)
        tokio::select! {
            res = rcv_fut => {
                if res.is_err() {
                    disconnected = true;
                    continue
                }

                let msg = res.unwrap();
                let res = handle_mqtt_msg(msg, &mut client, &mut app).await;
                if let Err(err) = res {
                    match err {
                        error::Error::SensorErr(err) => {
                            if let dist_sensor::SensorError::LunaErr(tf_luna::error::Error::ChecksumFailed) = err {
                                log::error!("Checksum Failed!")
                            }
                        }
                        _ => disconnected = true
                    }
                }
            },
            res = trg_fut => {
                if let Err(err) = res {
                    log::error!("Sensor erred while reading: {}", err);
                    continue
                }
                if handle_trigger(&mut client, &mut app, res.unwrap()).await.is_err() {
                    disconnected = true;
                }
            },
            // Timeout so we send heartbeat to client even if we dont manually zero or detect
            _ = timeout => {
                log::trace!("Timeout to send heartbeat...")
            }
        }
    }
}

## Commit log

2023-02-18 Setup sensor node docker
2023-02-27 add failure handling to sensor node
    [main.rs]
2023-03-02 Improve reliability when gateway loses power
2023-03-17 Implement tf-luna driver
2023-03-17 Integrate tf-luna driver
2023-03-30 Add support for le-potato uarta header pins
2023-04-04 Make fake sensor more random, else zero causes it to freeze.
2023-04-06 Make dhcpcd try to get a lease forever before starting sensor node
2023-04-06 Give more time to connect to broker
    [main.rs]
2023-04-15 Fix Gui updates removing popups, and add log files
    [main.rs]
2023-04-17 Make sensor node resilient to checksum failures
    [main.rs]
2023-04-26 Increase sensor debounce to 2s This should ensure that if the vehicle is going slow, we do not detect the front and rear wheels.
2023-05-19 Add CAD files.
    [Le Box.stl]
